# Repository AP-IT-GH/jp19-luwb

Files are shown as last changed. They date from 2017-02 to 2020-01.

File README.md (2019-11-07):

# Internet Of Things - *Location Ultra Wide Band*

## Angular
Build Status (https://dev.azure.com/LUWB/LUWB/_build/latest?definitionId=1&branchName=master)

## API
Build Status (https://dev.azure.com/LUWB/LUWB/_build/latest?definitionId=2&branchName=master)

**Teammembers**
* Hector Brasfalean
* Davy Cools
* Jens Peeters

## Summary
*Het lokaliseren van een robot/drone (indoor) door middel van Ultra Wide Band technologie. Dit gaan we visueel weergeven. We zullen de robot/drone ook op een autonome manier kunnen verplaatsen.*

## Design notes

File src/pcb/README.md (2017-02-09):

# PCB

In deze map verzamel je op een gestructueerde manier de bron bestanden voor het
PCB ontwerp.

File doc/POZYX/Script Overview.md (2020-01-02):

# Script Overview
## Dit is de documentatie van de POZYX Scripts
Onder src/Pozyx vind je 3 mappen met scripts het gebruik ervan wordt hieronder uitgelegd.

## 1 PozyxSoftware
Om deze scripts te gebruiken moet de Pozyx software aan het runnen zijn op een computer en moet er een Pozyx toestel met USB-kabel verbonden zijn.

### 1.1 connectLocal.py
Dit script verbind met de Pozyx software op een computer in het lokale netwerk.
Het print de coördinaten in de terminal en kan deze exporteren naar een txt-file.
Het IP-adres van de host waar de software op draait moet ingevuld worden onder host.

### 1.2 connectCloud.py
Dit script verbind met de software via de cloud gebruik makend van een topic, username en password.
Daarna worden de coördinaten geprint in de terminal.
Het topic, username en password moeten in het script ingevuld worden, en kan men vinden in de Pozyx software.

## 2 PozyxRPi
Dit zijn vooral test scripts en worden niet meer gebruikt.

### 2.1 pyTest.py
Dit script kijkt of er een Pozyx toestel is aangesloten.
Als er geen error wordt gegeven is alles in orde en is het toestel juist verbonden.

### 2.2 readingData.py
Kijkt na of het succesvol data uit het toestel kan halen.
Als "0x43" wordt geprint is alles in orde.

### 2.3 UWBsettings.py
Dit script haalt de UWB instellingen uit het toestel en print deze.

### 2.4 positioning.py
Dit script haalt de positie uit de direct verbonden tag en print dit af in de terminal.
De coördinaten kunnen ook geëxporteerd worden naar een txt-file

## 3 PozyxStandalone
Dit zijn de scripts waar we gebruik van maken en die niet afhankelijk zijn van de Pozyx software.
Bij de meeste scripts moeten er dingen worden ingesteld, hiervoor maken we gebruik van config-files.

### 3.1 Config-files
Omdat de meeste scripts dezelfde instellingen nodig hebben, zijn er config-files.

Er zijn 2 soorten files:

1. scripts die de vragen stellen over de instellingen
2. ini-files waarin de instellingen worden opgeslagen

We hebben 2 aparte config-files gemaakt:

1. Coördinaten en de ID's 
2. Exporteren

#### 3.1.1 createConfigFile.py
Dit script stelt de vragen voor de coördinaten en ID's:

1. Geconnecteerde toestel
2. Remote toestel(Meestal de tag)
3. ID's en coördinaten van de anchors

Deze slaagt deze waarden dan op in config.ini.

#### 3.1.2 config.ini
Hierin worden de ingestelde waarden van createConfigFile.py opgeslagen.
En deze file wordt gelezen door al de scripts die de coördinaten en ID's nodig hebben.

#### 3.1.3 createExportFile.py
Dit script stelt de vragen over het exporteren:

1. Exporteren naar een file?
2. Naam van de file
3. Exporteren via MQTT?
4. MQTT Host
5. MQTT Topic
6. MQTT ClientID
7. Exporteren via API?
8. API URL
9. API MAC Name

Deze slaagt al deze waarden dan op in export.ini

#### 3.1.4 export.ini
Hierin worden de ingesltelde waarden van createExportFile.py opgeslagen.
Deze file wordt dan ingelezen door de scripts die de export-settings nodig hebben.

### 3.2 Scripts
Hier staan de scripts die iets uitvoeren op het Pozyx toestel.

#### 3.2.1 discoverDevices.py
Het zoekt naar al de Pozyx toestellen binnen bereik met dezelfde UWB-instellingen vanuit het standpunt van het geconnecteerde toestel.
En print deze naar de terminal.

#### 3.2.2 setCoordinates.py
Dit script zet de ingestelde coördinaten in het geheugen van die toestellen.
Daarna worden al de coördinaten nog geprint ter controle.
Hierna kan getCoordinates.py uitgevoerd worden.
Dit is niet nodig voor positioning.

#### 3.2.3 getCoordinates.py
Deze haalt de coördinaten van de toestellen uit het geheugen van die toestellen en print deze naar de terminal.
Dit kan gebruikt worden na setCoordinates.py.

#### 3.2.4 setupAnchors.py
Dit wordt uitgevoerd op het remote device (tag).
Eerst wordt de device list leeg gemaakt. Daarna worden de ID's en coördinaten van de anchors opgeslagen in het geheugen van het device.
Optioneel kan dit worden opgeslagen in het flash-geheugen, maar dit staat in commentaar voor test doeleinden.
Hierna kan getDeviceCoordinates.py worden uitgevoerd.
Dit is nodig om positioning te kunnen uitvoeren.

#### 3.2.5 getDeviceCoordinates.py
Dit script wordt uitgevoerd op het remote device (tag).
Deze haalt de coördinaten van de anchors uit het geheugen van het device en print deze in de terminal.
Dit kan worden uitgevoerd na setupAnchors.py

#### 3.2.6 positioningTag.py
Dit is het belangrijkste script.
Dit wordt uitgevoerd op het remote device (tag).
Om dit script te kunnen uitvoeren moet setupAnchors.py eerst uitgevoerd zijn.
Eerst wordt de positie van de tag berekend en wordt die geprint naar de terminal.
Vervolgens wordt afhankelijk van de export-settings de positie geëxporteerd naar een file, via MQTT of naar de API.
Dit script zit in een loop en dient manueel gestopt te worden.

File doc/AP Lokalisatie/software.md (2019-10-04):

# 1. Software
## 1.1 Gebruikte software
-	Tag + anchors met Arduino (C/C++)
-	Data wordt doorgestuurd door de Raspberry Pi (python script)
-	Data wordt opgeslagen in een ASP.NET server
-	Data wordt visueel weergegeven in Angular
## 1.2 Software structuur
### 1.2.1 Tag en Anchor
Via de DWM1000 chips wordt de afstand tot de tag bepaald. De anchors die gebruik maken van een Arduino Pro Mini sturen hun data door over een Ethernet kabel naar het adres 192.168.3.3. De data wordt verstuurd in JSON formaat en ziet er als volgt uit:  
{"MAC_TAG":"TAGx","MAC_ANCHOR":"ANCHORy","DISTANCE":z}  
Met: x het tagnummer, y het anchornummer en z de afstand van de anchor tot aan de tag  
Voorbeeld: {"MAC_TAG":"TAG5","MAC_ANCHOR":"ANCHOR1", "DISTANCE":5}
### 1.2.2 Raspberry Pi
De Raspberry Pi doet 2 dingen. Langs de ene kant slaagt deze de data via een php apache server op en langs de andere kant stuurt deze de data door via MQTT.
#### Oude manier
- Het index.php bestand slaat bij een POST van data de data op als volgt:
1. Maakt de map data aan in /var/www/html indien deze nog niet bestaat.
2. Maakt in de map data een map TAGx aan met x = het tagnummer in de data van de POST indien deze nog niet bestaat.
3. Maakt in de map TAGx een bestand ANCHORy aan met y = het anchornummer in de data van de POST indien deze nog niet bestaat.
4. Schrijft in het bestand ANCHORy de afstand samen met datum op. Deze data wordt opgeslagen in het volgende formaat:   
distance,unixtimestamp  
Met: distance de afstand van anchor naar tag en unixtimestamp de datum  
Voorbeeld: 5,1557920157  
- Het postscriptMQTT.py stuurt de data door via MQTT om de 200 ms.
1. Leest de mappen uit die zich in de data map bevinden (/var/www/html/data).
2. Het script staat ingesteld om enkel de data uit de map TAG5 te lezen.
3. Alle bestanden in de TAG5 worden uitgelezen en de data wordt doorgestuurt via MQTT in het volgende formaat:   
TAGx;ANCHORy;distance;unixtimestamp
Met: x het tagnummer, y het anchornummer, distance de afstand van anchor naar tag en unixtimestamp de datum  
Voorbeeld: TAG5;ANCHOR1;25;1557475973
#### Nieuwe manier (voorkeur)
- Het listenAndPostScriptMQTT.py script luistert naar de socket. Stuurt bij het ontvangen van data de data door via MQTT.
1. Leest de config.ini file uit voor configuratie.
2. Luistert naar de socket op ingestelde ip + poort.
3. Stuurt de ontvangen data door via MQTT naar de ingestelde topic.
Het formaat van de doorgestuurde data is:
TAGx;ANCHORy;distance;unixtimestamp
Met: x het tagnummer, y het anchornummer, distance de afstand van anchor naar tag en unixtimestamp de datum  
Voorbeeld: TAG5;ANCHOR1;25;1557475973
### 1.2.3 ASP.NET server
De ASP.NET server haalt de data op van MQTT. Deze data wordt dan opgeslagen in de database.
### 1.2.4 Webapplicatie met Angular framework
Op de website wordt visueel weergegeven waar de tag zich bevindt t.o.v. de anchors.

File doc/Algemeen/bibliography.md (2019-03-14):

# 1	Sensor
## 1.1	Protocol
Pozyx creator tutorial gebruik makend van arduino: https://www.pozyx.io/documentation/creator/arduino/ready-to-range  
TWR vs TDOA:  
https://www.pozyx.io/pozyx-academy/positioning-protocols-explained  
https://www.infsoft.com/blog-en/articleid/305/uwb-two-localization-techniques-in-comparison  
TWR verklaring: https://www.sewio.net/uwb-technology/two-way-ranging/  
T(D)oa verklaring: https://sites.tufts.edu/eeseniordesignhandbook/files/2017/05/FireBrick_OKeefe_F1.pdf  
Arduino Motor uitleg: https://howtomechatronics.com/tutorials/arduino/arduino-dc-motor-control-tutorial-l298n-pwm-h-bridge/  
Arduino motor Tutorial: https://hackerstore.nl/PDFs/Tutorial298.pdf

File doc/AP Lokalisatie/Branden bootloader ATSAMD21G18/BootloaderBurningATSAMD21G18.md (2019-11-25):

# Stappenplan branden bootloader ATSAMD21G18

## 1. Installeren software
Voor het branden van de bootloader hebben we een bepaald programma nodig genaamd 'Atmel Studio'. 
De URL waar u dit programma kan downloaden is het volgende : [https://www.microchip.com/mplab/avr-support/atmel-studio-7](https://www.microchip.com/mplab/avr-support/atmel-studio-7)
## 2. Downloaden bootloader github
U zal de volgende repository moeten downloaden zodat u de bootloader voor de ATSAMD21G18 ter beschikking heeft.
[https://github.com/sparkfun/SAMD21_Dev_Breakout](https://github.com/sparkfun/SAMD21_Dev_Breakout)
## 3. Aansluitingen hardware
U sluit de J-link EDU aan via usb op uw computer. U sluit de 20 pin naar 10 pin adapter (J-TAG) aan op de J-link EDU. Vervolgens sluit je de ribbon cable aan op de adapter. De volgende signalen zijn de belangrijkste bij het aansluiten van de header:

 - SWDIO ( Grijze female jumper )
 - SWCLK ( Witte female jumper ) 
 - GND ( Paarse en groene female jumper ) 
 - VCC ( Gele female jumper ) 
 - RESET ( Blauwe female jumper ) 
 
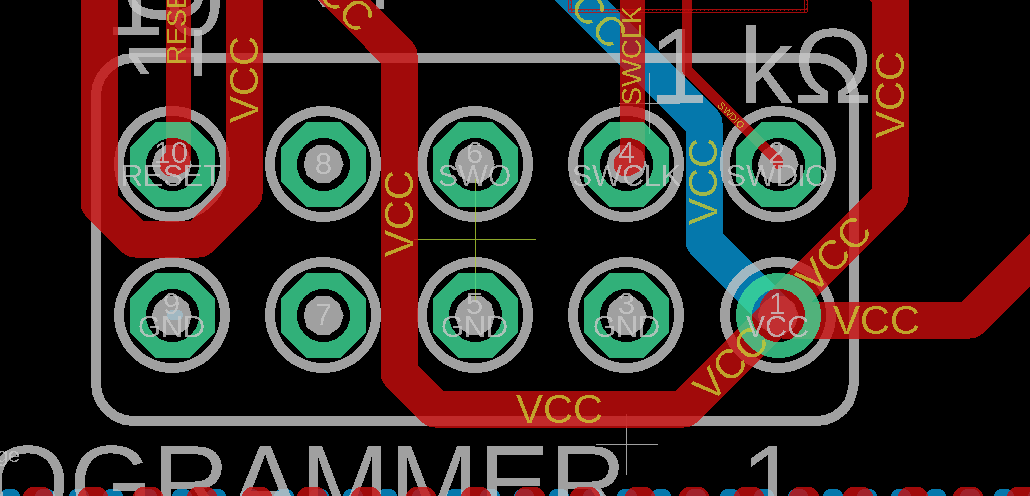
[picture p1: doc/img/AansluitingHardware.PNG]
Aansluitingen hardware

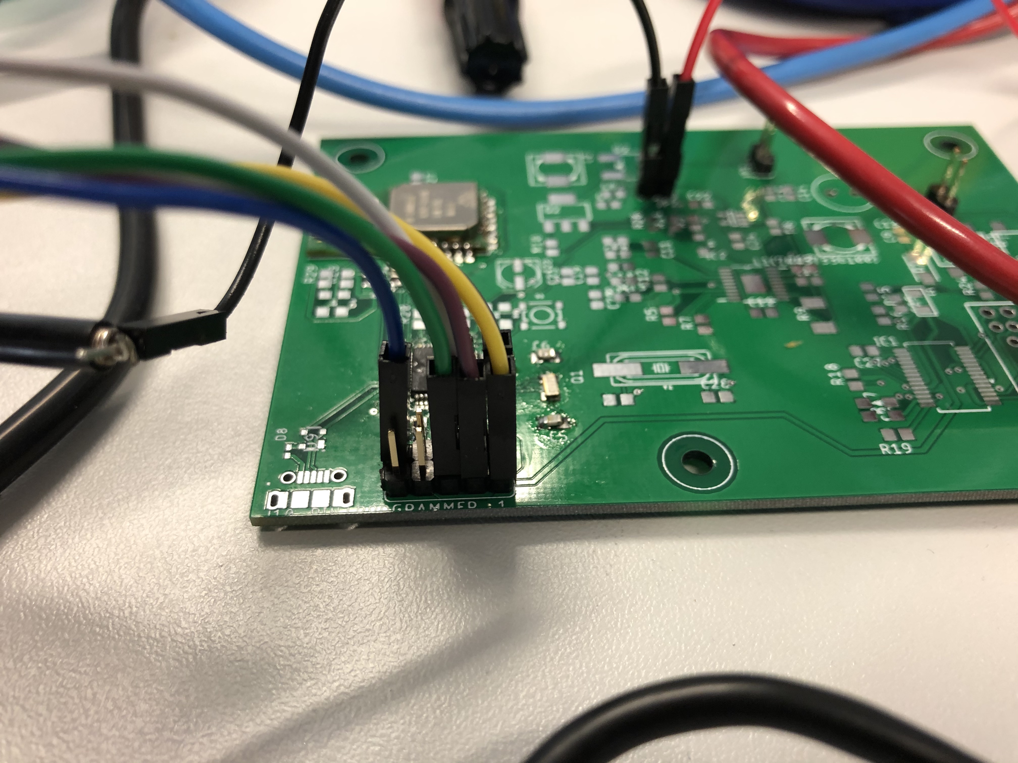
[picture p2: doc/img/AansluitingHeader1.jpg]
Aansluitingen hardware 1

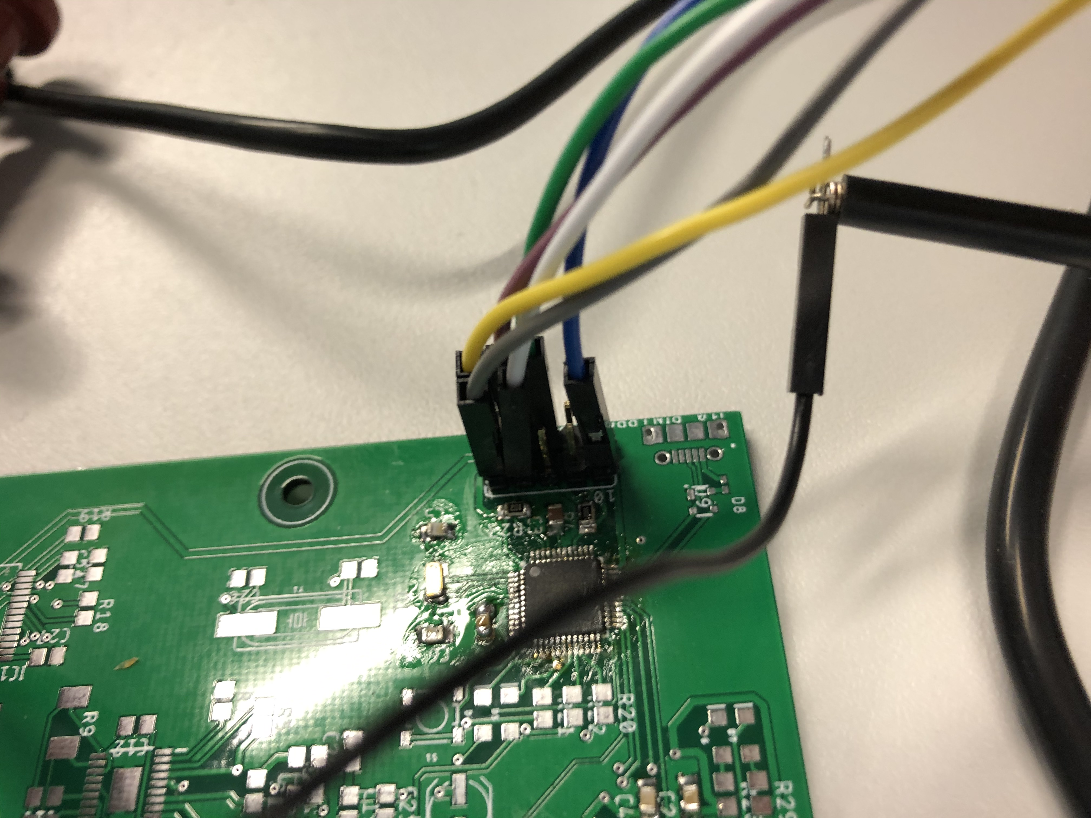
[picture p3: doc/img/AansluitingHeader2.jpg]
Aansluitingen hardware 2

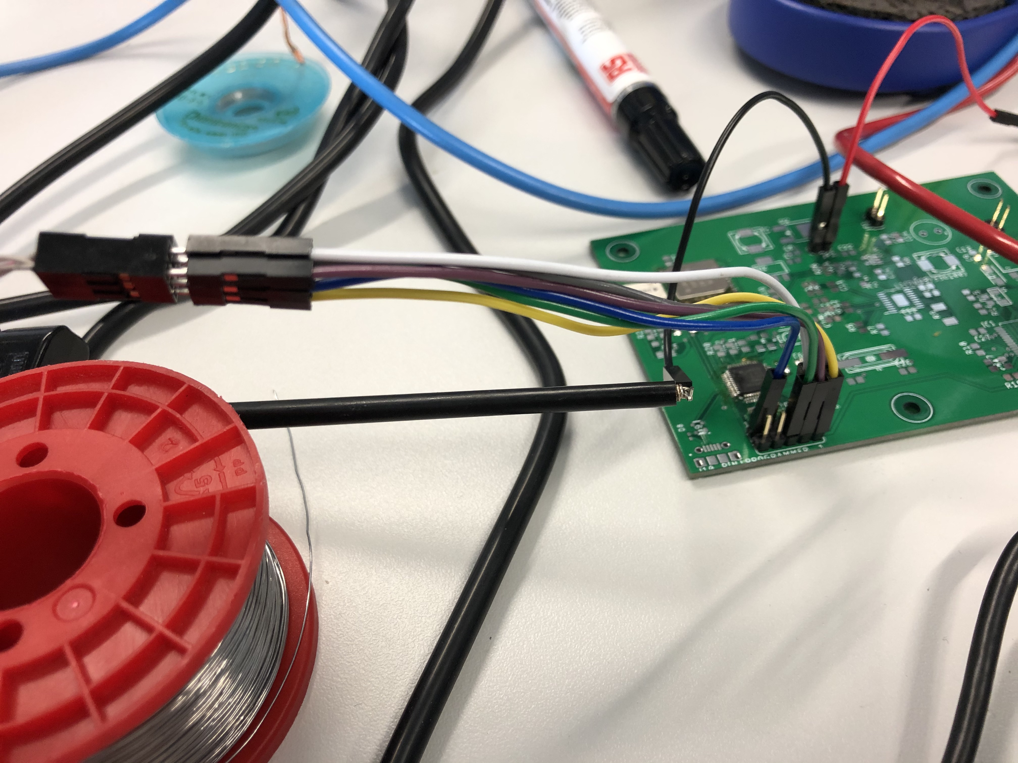
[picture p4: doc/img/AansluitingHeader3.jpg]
Aansluitingen hardware 3


## 4. Verwijderen ATSAMD21G18 chip
Zodra het programma geïnstalleerd is, zal u indien u het programma opstart het volgende scherm bekomen:
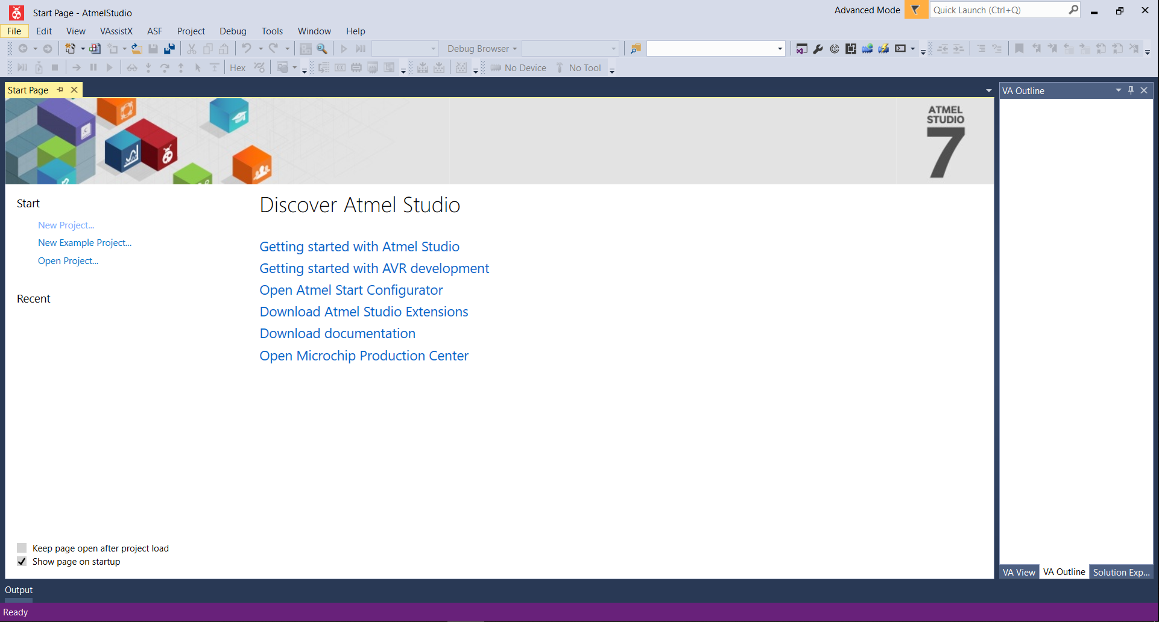
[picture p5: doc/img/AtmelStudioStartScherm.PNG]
Atmel Studio start scherm


Vanuit dit scherm gaat u naar **'Tools => Device programming'**. 
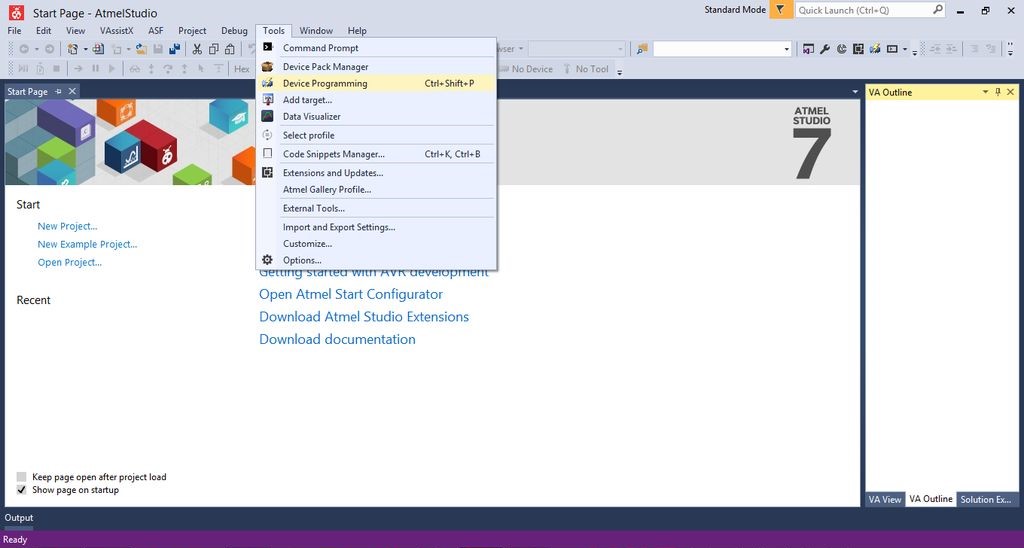
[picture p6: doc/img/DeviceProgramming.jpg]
Atmel Studio tools


Een nieuw venster zal verschijnen. Nu kan u uw J-LINK EDU connecteren met uw laptop via een USB-poort. Het resultaat zou moeten zijn dat u bij het nieuwe scherm onder **'Tool'** een drop-down heeft, in deze drop-down zou dan de J-LINK moeten staan. Deze kan u dan ook selecteren.
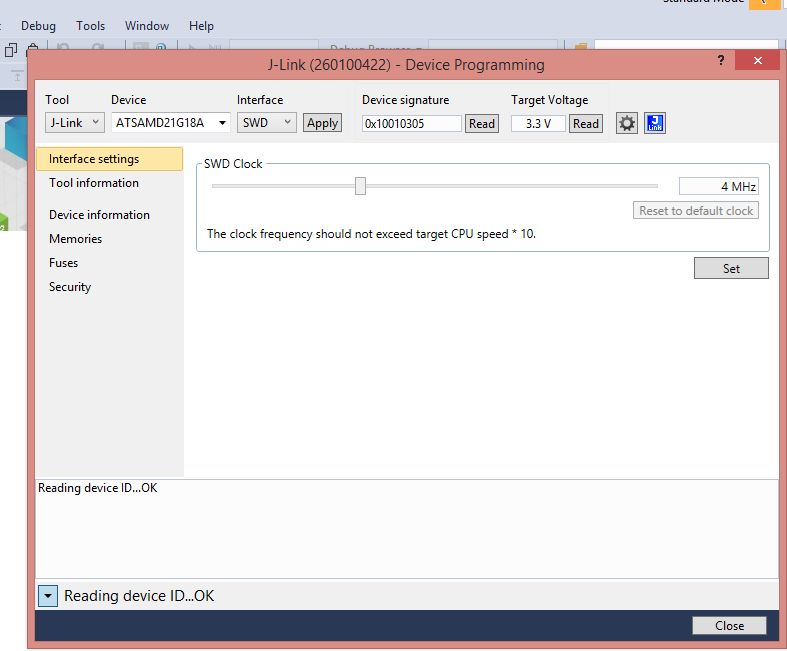
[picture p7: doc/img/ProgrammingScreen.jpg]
Atmel Studio programming


Bij de term **'Interface'** moeten we ook specificeren welke interface we zullen gebruiken. Deze moet ingesteld staan op **'SWD'**. Hierna kan u op **'Apply'** drukken.

Indien alles correct aangesloten zou zijn, moet u de ATSAMD21G18 zelf van spanning voorzien ( 3.3V ). Nadat u dit gedaan hebt, kan u onder de term **'Target Voltage'** de knop **'Read'** indrukken. Als alles correct aangesloten zou zijn moet u hier 3.3V uitlezen. Indien er wat onduidelijk is, verwijs ik naar de foto hierboven vermeld.

Vervolgens gaat u naar **'memories'** aan de linkerkant van uw scherm en zal u de chip verwijderen. U doet dit door **'erase chip'** te selecteren uit de drop-down en vervolgens op de knop **'erase'** te drukken. Op het output scherm zou u het volgende moeten bekomen : "Erase...Ok".
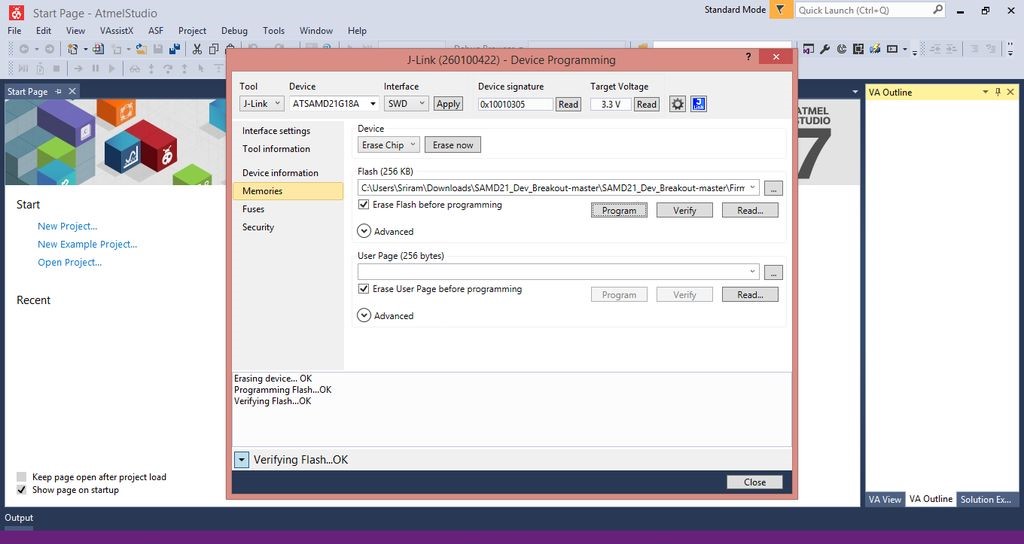
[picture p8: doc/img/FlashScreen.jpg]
Atmel Studio erase


## 5. Branden bootloader
Nu kan u de zekeringen of **'fuses'** programmeren bij de **'interface settings'** aan de linkerkant van het scherm. Dit doet u door naar het 'fuses' scherm te gaan en op de knop **'program'** te drukken. Dit verifieert de interne registers van de ATSAMD21-chip.
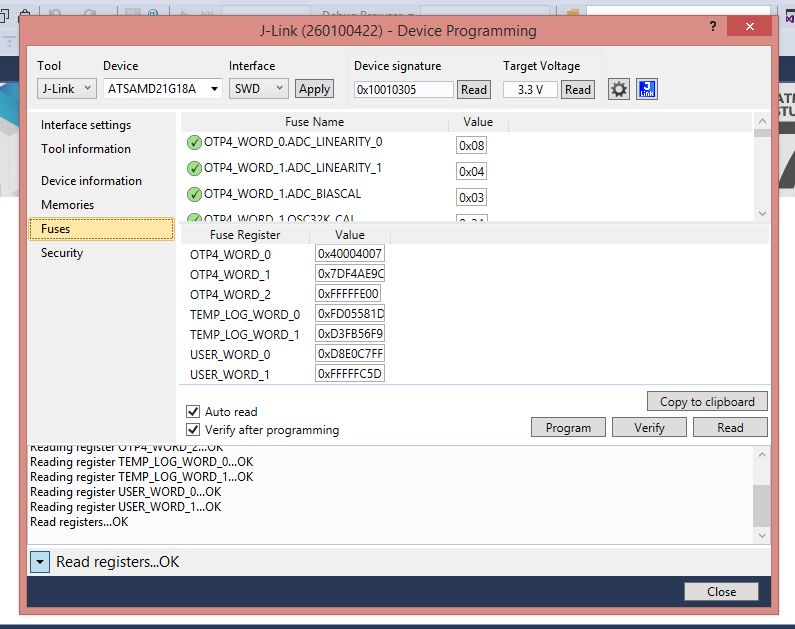
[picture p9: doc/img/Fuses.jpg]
Atmel Studio fuses


Uiteidenlijk gaan we terug naar het menu **'memories'**. Klik onder de balk met het label **'flash'** op het pictogram **'Bladeren naar bestand'** en zoek de map waarin u het zip bestand hebt opgehaald dat u van github hebt gekregen met het label "SAMD21_Dev_Breakout-master" onder Firmware, zorg ervoor dat u naar alle bestandstypes zoekt, want we zullen het samd21_sam_ba_sparkfun.bin bestand gebruiken. Klik op het bestand en selecteer openen. Klik ten slotte op de knop **'Program'** en u krijgt een antwoord in het output scherm met de melding: "Verifying Flash...OK". Gefeliciteerd, je hebt de SAMD21-chip succesvol opgestart!

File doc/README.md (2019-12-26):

# Documentatie
# Algemeen
Alle algemene informatie vindt u in de folder Algemeen. Dit gaat over de gebruikte techniek, wat LUWB is, de bibliografie, ...

# Project AP Lokalisatie
Alle info in verband met het zelf gemaakt project zit in de map AP Lokalisatie

# Project POZYX
Alle info in verband met het POZYX zit in de map POZYX

# De website en de server
Alle info in verband met de website en de server zit in de map Website en server

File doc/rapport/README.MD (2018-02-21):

Plaats in deze map alle documenten die deel uitmaken van je eindrapport

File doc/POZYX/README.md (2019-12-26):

# Documentatie

In deze map vindt u alle documentatie van het POZYX project.

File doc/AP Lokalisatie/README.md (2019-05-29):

# Documentatie

In deze map vindt u alle documentatie van het AP lokalisatie project.

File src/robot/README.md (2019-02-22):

# Robot

In deze map verzamel je op een gestructueerde manier de bron bestanden voor de
Robot applicatie.

SMART SYSTEMS KIT #19

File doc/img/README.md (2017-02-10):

# Images

Gebruik deze folder voor het verzamelen van afbeeldingen en maak een link naar het gewenste document.

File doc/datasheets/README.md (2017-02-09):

# Datasheets
In deze map verzamel je de gebruikte datasheets. Upload ze als pdf.

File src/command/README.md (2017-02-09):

# Command Center

In deze map verzamel je op een gestructueerde manier de bron bestanden voor de
Command Center applicatie.

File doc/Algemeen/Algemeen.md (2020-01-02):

# Location Ultra Wide Band
## 1 Wat is UWB?
UWB (Ultra Wide Band) is een draadloze technologie die gebruikt wordt om met hoge snelheid grote hoeveelheid data door te sturen. Het UWB signaal is zeer robust en kan door dunne muren. Wij gebruiken deze techniek voor het localiseren van een beweegbaar object (drone/robot). 

## 2 Algemene begrippen/technologiën
### 2.1 MQTT
MQTT staat voor Message Queueing Telemetry Transport. Dit is een machine-tot-machine data transfer protocol. MQTT is gebasseerd op TCP/IP en heeft een kleine overhead (2-byte header). MQTT heeft een centrale bemiddelaar, de MQTT-broker. Deze interface is voor alle verzonden berichten. De betrokken apparaten communiceren dus niet met elkaar en kennen elkaar dus onderling niet. Het is de taak van de broker om berichten te accepteren en door te geven aan de juiste ontvanger(s).

### 2.2 DWM module
De DWM module, of specifieker de DWM1000 module is gebasseerd op Decawave's DW1000 IC. Deze module maakt het mogelijk om objecten real-time te lokaliseren (RTLS: real time location systems) tot op een nauwkeurigheid van 10cm binnen. De datacommunicatie kan gaan tot een snelheid van 6,8 Mbps met een bereik tot 300 meter. 

### 2.3 SQL
SQL staat voor Structured Query Language. Dit is een ANSI/ISO-standaardtaal voor databasemanagement systemen (DBMS). Dit is dus een gestandaliseerde taal die gebruikt wordt voor het opslagen, opvragen, aanpassen en verwijderen van gegevens in een relationele database.

### 2.4 Relationele Database
Een relationele database is een database die is opgebouwd volgens het relationeel model. Alle gegevens worden opgeslagen in tabellen waarbij rijen de soortgelijke informatie (records) vormen en de kolommen zijn de informatie die voor elk record moet worden opgeslagen. Verschillende tabbellen kunnen met elkaar verbonden worden door een extra kolom waarin een verwijzing staat naar een record van een andere tabel.

## 3 De 2 projecten
### 3.1 Project 1: LUWB self-made
Dit project is een eigen ontworpen systeem dat gebruik maakt van de UWB technologie. De bedoeling is dat we met zelfgemaakte anchors een robot kunnen localiseren met een tag aan boord. De tag communiceerd dan met de anchors en er wordt berekend hoe ver deze zich van elkaar bevinden. Op basis hiervan wordt dan berekend waar de robot zich op dat moment bevindt. Dit wordt dan visueel weergegeven.

#### 3.1.1 Hoe werkt het?
##### 1. Huidig concept:
De tag (robot) die werkt op een Arduino met een DWM module communiceerd met de anchors die werken op 2 Arduino's met een DWM module. Deze 2 delen dan informatie met elkaar uit via UWB en zo wordt er bepaald wat de afstand is tussen de tag en de anchors. Deze data wordt doorgestuurd over een ethernetkabel naar een switch en komt terecht bij een Raspberry Pi. Op deze Raspberry draait dan een script die deze data op zijn beurt doorstuurt via MQTT. Een server die lokaal of op een cloud draait lijst dan deze data uit en slaagt deze op in een SQL database. Met deze data wordt er berekend waar de tag (robot) zich exact bevindt.  Dan wordt vanuit een webapplicatie die gemaakt is met Angular de data opgevraagd. Dit wordt dan visueel weergegeven op de website.

#### 2. Veranderingen die zijn gebeurd:
De data werd eerst rechtstreeks doorgestuurd naar de server die in de cloud stond via threading in het python script. Dit zorgde voor verschillende problemen en werkte vrij traag. Ook was het luisteren naar de socket via een apache server niet de beste manier.
Dit is vervangen door 1 enkel pythonscript die luistert naar de socket en de data doorstuurd via MQTT. De server die op het moment lokaal draait op een laptop wacht op zijn beurt af tot er nieuwe MQTT data beschikbaar is.

#### 3. Veranderingen die nog moeten gebeuren:
1. Op het moment werken de anchors op 2 arduino's. Deze worden vervangen door 1 enkele chip genaamd atsamd21g18.
2. Het voorzien van spanning via een adapter wordt vervangen door PoE (Power over Ethernet).
3. Het visueel weergeven moet zowel op een website als op een app kunnen weergegeven worden.
4. De drone of robot moet kunnen worden bestuurd via de app/website door een lijn te tekenen en deze dan te laten volgen. Voorlopig kan de robot via een aparte app wel verplaatst worden door middel van 4 knoppen (voorruit/achterruit/links/rechts).

### 3.2 Project 2: Pozyx
Dit is een systeem van Belgische makelij dat we hebben aangekocht. Dit systeem maakt ook gebruik van UWB. De bedoeling was dat we de tag op een robot konden plaatsen en deze dan zo kunnen traceren. We hebben het systeem op 2 wijze gebruikt nl. Out-Of-The-Box: waarvoor het gemaakt is. En met onze zelfgemaakte software.

#### 3.2.1 Out-Of-The-Box
Het systeem is gemaakt om snel bruikbaar te zijn door middel van de bijhorende Pozyx software. De software moet geïnstalleerd worden op een computer en deze moet verbonden worden met 1 van de Pozyx toestellen. De andere toestellen moeten gewoon van stroom voorzien worden en zullen allemaal met elkaar communiceren. In de software worden dan alle toestellen weergegeven. En kan je autocalibratie laten uitvoeren, maar dit is niet accuraat dus is manuele calibratie aanbevolen. Vervolgens kan de tag gelocaliseerd worden en wordt dit getoont op de kaart. Ook kan de positie geëxporteerd worden via MQTT over het lokale netwerk of via de cloud.

#### 3.2.2 Zelfgemaakte software
Omdat we niet afhankelijk wouden zijn van de Pozyx software, hebben we zelf software geschreven in de vorm van Python scripts die dan wel de Pozyx hardware gebruikt. Er zijn scripts geschreven die nog afhakelijk waren van de Pozyx software voor testen, maar nu zijn er script die volledig onafhankelijk zijn van de software. Om het systeem te gebruiken moeten al de anchors worden geïnstaleerd. 1 anchor moet met een USB-kabel worden aangesloten aan een Raspberry Pi. Al de andere anchors moeten van stroom worden voorzien. Vervolgens moet je met ons config script alle coördinaten en ID's van de anchors instellen. Daarna voer je de setup uit op de tag als deze van stroom is voorzien. En dan is het mogelijk om de positie van de tag te bepalen. Die positie wordt in de terminal geprint en kan ook afhankelijk van de export-instellingen, worden geëxporteerd naar een file, via MQTT of naar de API welke dan zichtbaar is op de website.

# Bronnen:
- POZYX: [pozyx](https://www.pozyx.io/)
- MQTT: [at-automation](https://www.at-automation.nl/knowledge-base/mqtt-message-queueing-telemetry-transport-wat-is-het/) [ct](https://www.ct.nl/achtergrond/iot-protocol-mqtt-betrouwbaar-data/)
- DWM: [decawave](https://www.decawave.com/product/dwm1000-module/) 
- SQL: [wikipedia](https://nl.wikipedia.org/wiki/SQL) 
- Relationele Database: [wikipedia](https://nl.wikipedia.org/wiki/Relationele_database)

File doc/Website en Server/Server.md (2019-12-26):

# Documentatie van de server

**Topics die aan bod zullen komen**
- Algemene informatie
- Opstarten van de server
	- default connection string
	- SQL Server Object
- Doel van de controllers
- Belangrijke methode's

## Algemene informatie

Er is gebruik gemaakt van een ASP.NET Core REST API met versienummer 3.0. De server is helemaal klaar om online gehost te worden via Azure. De database kan zowel lokaal als online op Azure gehost worden. 

## Opstarten van de server

**Lokaal**
Bij het openen van de server is het aangeraden om gebruik te maken van Visual Studio 2019 of nieuwer. Het openen kan gemakkelijk door de solution Server.sln te openen, deze is te vinden in de map Server. Hierna moet je enkel nog op IIS Express klikken en de server zal opstarten, hierdoor zal database automatisch gegenereerd worden.

> **Note:** Zorg er voor dat de default connection string op de lokale database staat ingesteld. Meer informatie vindt je hieronder.

### Instellen van de default connection string

De default connection string beschrijft de locatie van de gebruikte database. Deze string vind je in de file 'appsettings.json'. Voor het gebruiken van een lokale database gebruik je volgende string:

**Server=(localdb)\\mssqllocaldb;Database=NaamDB**
NaamDB mag eender welke gekozen naam zijn voor de lokale database.

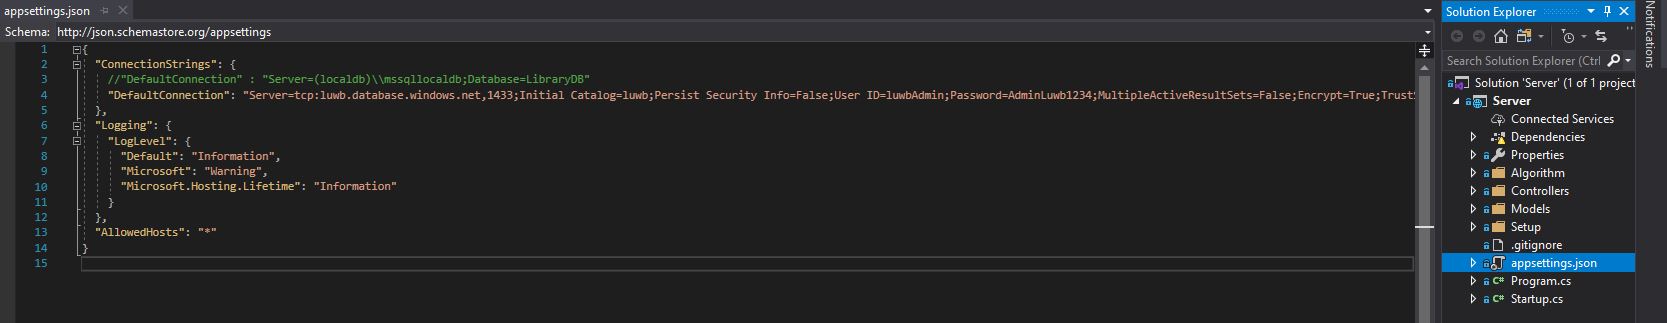
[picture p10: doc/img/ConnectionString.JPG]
ConnectionString


Voor het gebruiken van een online database moeten er verschillende variabele meegeven worden. Om te weten welke variabele je moet meegeven, moet je kijken in de documentatie van het gebruikte hostplatform. 

> **Note:** De 2de connection string in de server is voor een database gehost op Azure. Bij het gebruiken van deze string moet je enkel het id, passwoord en de locatie van de server aanpassen.

### Locatie van de lokale database
Als je gekozen hebt om de database lokaal op te slagen, kan je deze als volgt terugvinden:
- Open de server
- Ga naar **View** => **SQL Server Object Explorer**

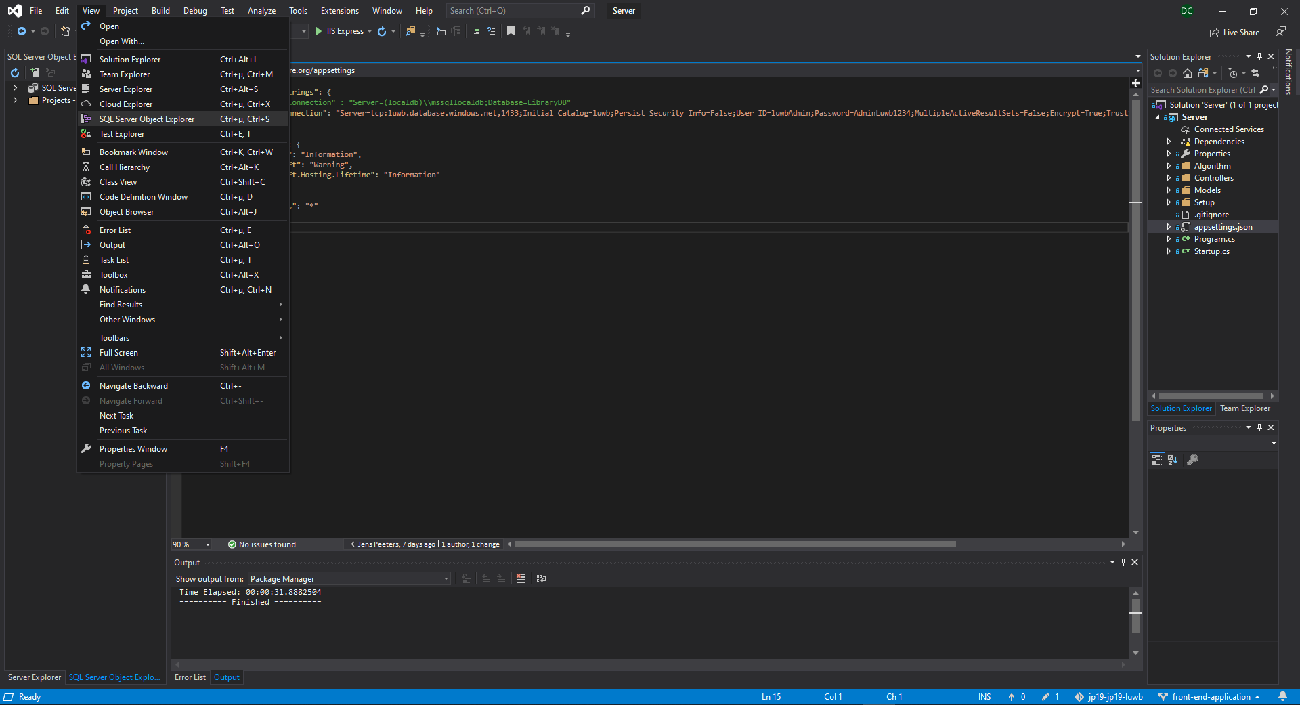
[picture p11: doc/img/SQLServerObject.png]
SQL Server Object


- Hierna open je de **SQL Server** => **Databases** => **{Gekozen DB naam}**

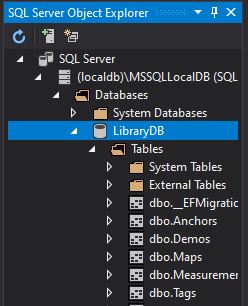
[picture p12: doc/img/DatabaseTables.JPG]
DatabaseTablest DatabaseTables


Alle data die in de database zit zal je ook hier kunnen terugvinden bij het debuggen.

## Doel van de controllers

### TagController
Via deze controller kan je alle tags aanspreken die opgeslagen zijn in de database alsook nieuwe tags toevoegen en bestaande tags verwijderen. Doel van de methodes:
- **GetTagsParam({parameters}):** Elke tag die voldoet aan de meegeven parameters zal worden teruggestuurd. Dit zal een lijst zijn van geen of meerdere tags.
- **GetTag(id:long):** Opvragen van 1 tag die de meegeven id bevat. De methode zal antwoorden met een NotFound als de tag niet gevonden is.
- **Addtag(tag: Tag):** Toevoegen van 1 tag die meegeven wordt in de body van de Post. De tag zal hier opgeslagen worden in de database.
- **UpdateTag(tag: Tag):** Updaten van de meegegeven tag. Als de meegeven tag niet bestaat in de database zal een NotFound worden teruggestuurd.
-  **UpdatePozyxTag(mac, xpos, ypos, zpos):** Updaten van de tag met meegegeven mac. Hierbij zal enkel de positie van de tag aangepast worden. Deze methode zal alleen worden opgeroepen door het Pozyx systeem.
- **DeleteTag(id: long):** Verwijderen van de meegeven tag. Wanner de tag succesvol is verwijderd zal een status 200 Ok worden teruggestuurd. Ook hier wordt een NotFound teruggestuurd bij een foute id.

### AnchorController
Via deze controller kan je alle anchors aanspreken die opgeslagen zijn in de database alsook nieuwe anchors toevoegen en bestaande anchors verwijderen. Doel van de methodes:
- **GetAnchorsParam({parameters}):** Elke anchor die voldoet aan de meegeven parameters zal worden teruggestuurd. Dit zal een lijst zijn van geen of meerdere anchors.
- **GetAnchor(id:long):** Opvragen van 1 anchor die de meegeven id bevat. De methode zal antwoorden met een NotFound als de anchor niet gevonden is.
- **AddAnchor(anchor: Anchor):** Toevoegen van 1 anchor die meegeven wordt in de body van de Post. De anchor zal hier opgeslagen worden in de database.
- **UpdateAnchor(anchor: Anchor):** Updaten van de meegegeven anchor. Als de meegeven anchor niet bestaat in de database zal een NotFound worden teruggestuurd.
- **DeleteAnchor(id: long):** Verwijderen van de meegeven anchor. Wanner de anchor succesvol is verwijderd zal een status 200 Ok worden teruggestuurd. Ook hier wordt een NotFound teruggestuurd bij een foute id.

### MeasurementController

- **CreateMeasurement(item: Measurement):** Toevoegen van 1 measurement die meegeven wordt in de body. Wanner zowel de tag als de anchor gevonden worden zal de measurement of worden geüpdate als deze al bestaat of worden toegevoegd. Als de tag of anchor ontbreekt zal er een NotFound worden teruggestuurd.
- **GetAllMeasurements():** Alle measurements zullen worden teruggestuurd in een lijst.
- **GetMeasurement(mac: string):** Opvragen van 1 specifieke measurement van een tag met als mac gelijk aan de meegegeven mac. De gevonden measurement zal dan worden teruggestuurd. Als er geen measurement gevonden is wordt er een NotFound teruggestuurd.

## Belangrijke methode's
**! Opgelet: Alles van MQTT wordt niet meer gebruikt, voor dit terug te kunnen gebruiken moet alles in de startup.cs uit commentaar gehaald worden waarbij het volgende staat geschreven: 'Disabled MQTT'.  Dit wordt niet meer gebruikt omdat bij het hosten bij Azure het gratis abonnement slechts 1 uur uptime geeft per dag en MQTT blijft 24/7 draaien, het nieuwe gebruikte systeem met post niet. !**

In de startup.cs: 

- **SetupMQTT():** Hier worden alle gegevens die nodig zijn voor MQTT opgehaald uit een bestand. Dit wordt niet meer gebruikt omdat we dit bestand niet mee uploaden naar Azure. De gegevens worden dus gewoon in de startup.cs klasse ingevuld.
- **client_MqttMsgPublishReceived(sender: object, e:MqttMsgPublishEventArgs):** Wordt getriggerd wanneer er een bericht gepubliceerd wordt op de MQTT topic
- **ConnectToBroker():** Connectie maken met de MQTT broker en subscriben op de ingestelde topic
- **SaveMeasurementInDB(payload: string):** Wanneer er een bericht op de MQTT wordt gepost, wordt er gecontroleerd of dit in het juiste formaat is. Wanneer het formaat overeenkomt zal de measurement worden geüpdate of aangepast wanneer deze nog niet bestond. Hierna wordt er gekeken of alle measurements van de tag in de meegestuurde measurement van hetzelfde tijdstip zijn. Als dit zo is zal de locatie van de tag opnieuw berekend worden.

In de Algorithm.cs:
- **Calculate(dataList: List<Data>):** Een data object bevat de afstand van een anchor tot een tag samen met zijn huidige locatie. Deze worden dan meegegeven naar de juiste methode. Voorlopig is dit slechts 1 methode.
- **calculateThreeCircleIntersection(x,y,r (3 keer)):** Deze methode berekend de locatie van de tag. Deze methode zal alleen maar weken bij 2 of 3 anchors. Bij het gebruik van meer anchors moet er een nieuwe methode worden aangemaakt.

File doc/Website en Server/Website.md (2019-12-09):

# Documentatie van de website

**Topics die aan bod zullen komen**
- Algemene informatie
- Opstarten van de website
- De verschillende componenten
- De verschillende services

## Algemene informatie

Deze server is gemaakt in Angular. Je kan deze files aanpassen en bekijken met verschillende programma's. Wij raden aan om het te openen met Visual Studio Code. De naam van de folder waar alle files zich bevinden is WebAppLUWB me als path \src\visualisatie\WebAppLUWB.

## Opstarten van de website
**Lokaal**
- Installeren van de dependencies: Voor het lokaal runnen van de website moet je de nodige dependencies en modules installeren. Hiervoor typ je 'npm install' in een terminal of Windows Powershell. 

> **Note:** Zorg er voor dat je bij dit en volgende commando's in de folder zelf zit of je in de terminal typt die je onderaan vindt bij Visual Studio Code.

- Het starten van de server kan zeer gemakkelijk door het commando 'npm start' in de terminal te typen. De webserver zal nu opstarten en je kan je website terugvinden onder het domein 'http://localhost:4200'. Je zal automatisch geredirected worden naar de homepage van de webserver (http://localhost:4200/home).

## De verschillende componenten

- **Home component:** Deze component bevat alle code voor het tonen van de home page. Op deze pagina vindt u een kleine samenvatting van de 2 projecten alsook een foto.
- **Map component:** Deze component bevat alle code voor het tonen van de map page. Hier worden alle anchors en tags getoond op een kaart.
- **PageNotFound component:** Deze component wordt weergegeven wanneer de gebruik een route ingeeft die niet bestaat.
- **TagsAndAnchors component:** Deze component bevat alle code voor het tonen van de anchors en tags in een lijst. Hier is het mogelijk anchors/tags te verwijderen/toevoegen/updaten.
- **Toolbar component:** Deze component bevat alle code voor het tonen van de toolbar. Dus wanneer er een nieuwe route nodig is of een bestaande wordt aangepast moet je de logica en de layout aanpassen in deze component. Via het [routerlink] attribuut kan je ingeven naar welke route er moet genavigeerd worden.

## De verschillende services

- **Callapi Service** Deze service wordt gebruikt voor alle gets/posts en puts naar de API. Hier is het dus belangrijk dat de variabele genaamd domain juist is ingesteld. Deze moet ingesteld zijn op de link waar de api zich bevindt.
> **Tip:** Als je de api lokaal runt zal dit de standaard link zijn en die is als volgt: https://localhost:44321/api/
> Na de laatste / komt de naam van de controller (bv.  https://localhost:44321/api/tags)

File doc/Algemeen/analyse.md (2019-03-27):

# Analyse

## Probleemstelling

Het indoor tracken van assets (drones/robots) door middel van een Ultra Wide Band (UWB) systeem dat we van scratch gaan maken.

## Deelproblemen

1.	Localisatie
-	Connecteren met de tag.
-	Bepalen van de x,y en z coördinaten van de tag.
2.	Visualisatie van anker en tag
-	Het visualiseren van de locatie van de tag ten opzichte van de anchors op een website.
-	De map moet juist gevisualiseerd moeten.
3.	Energieverbuik
-	Leveren van genoeg vermogen en proberen het vermogen van de anchors en tags zo klein mogelijk te houden.
4.	Nauwkeurigheid
-	Bij een te kleine omgeving is er slechte nauwkeurigheid.
-	Bepalen van de locatie zo nauwkeurig mogelijk.
5.	Verzenden van data
-	Zorgen dat de data aankomt naar de server.
6.	Beweging
-	De beweging van de tag d.m.v. robot/drone.
-	Bestuur afstand voor manuele beweging
7.	App
-	Het besturen van onze robot/drone.
-	De lokalisatie van de robot/drone zien.
8.	Database
-	Er moet een historiek van de data worden weergegeven.
9.	Omgeving
-	De omgeving mag niet te klein om onze functie te laten werken.
-	De omgeving is binnen.
10.	Snelheid
-	Snelheid van data
-	De robot/drone mag niet botsen tegen de muur of obstakel

## Mindmap
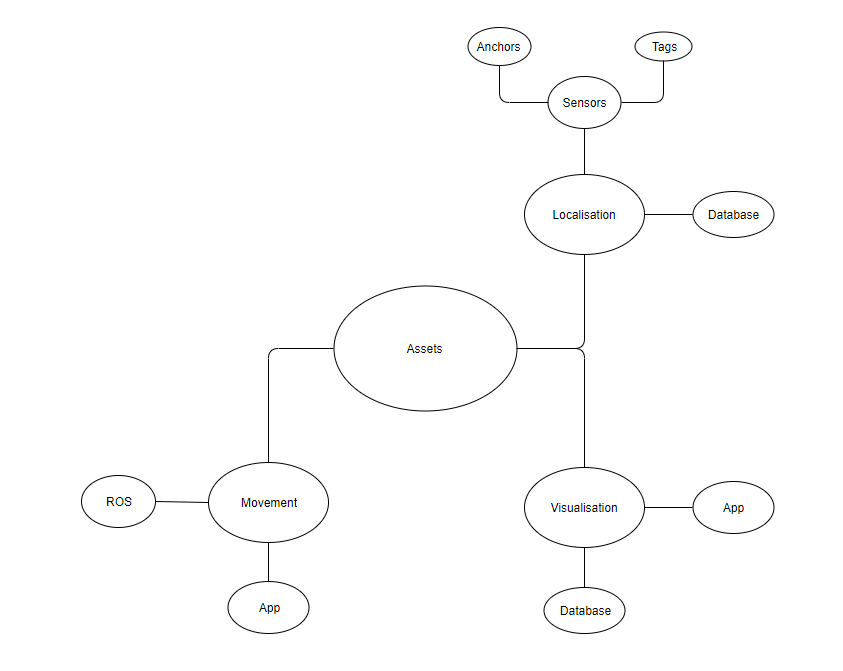
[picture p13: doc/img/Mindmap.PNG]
Github Logo Mindmap


## Beschrijving

Een transportbedrijf, dat ook goederen stockeert, wil analyseren of de workflow efficiënter kan. Dit zou kunnen door manueel te kijken of alle goederen efficiënt doorheen het bedrijf bewegen door bij elke verandering van plaats, dit op te schrijven en nadien dit te bekijken. Dit vergt natuurlijk een hele hoop administratie en manueel werk. We zouden een systeem kunnen opstellen dat alle goederen traceert binnen het bedrijf en dit logt naar een centrale database. We zouden in dit systeem gebruik kunnen maken van een drone, die vanuit een database alle locaties en dus ook routes kan ophalen en worden weergegeven op een plattegrond van het bedrijf via een mobiele app of website. De plaatsbepaling kan op enkele manieren gebeuren, maar omdat dit indoor is en toch wel een goede nauwkeurigheid vereist, is GPS geen optie. In dit geval zouden we gebruik kunnnen maken van UWB technologie. Ultra-wideband is een draadloze technologie waarmee een grote hoeveelheid gegevens bij een hoge snelheid kan worden verzonden. Dit is mogelijk door de gegevenspakketjes over een brede frequentieband te spreiden, waardoor ze parallel kunnen worden verzonden. Daardoor zijn gegevenssnelheden tot 1GB per seconde over een afstand van 10 meter mogelijk. De drone zal dan door het magazijn kunnen vliegen en gevisualiseerd worden via een website of een mobiele app en indien nodig, kunnen er bewegingen uitgevoerd worden door een beweging op het scherm van een smartphone. Om te beginnen gaan we testen met een kleine robot. Deze robot zal werken van op de grond.

## Hardware analyse

### Hardware blokdiagram

#### Tag

Github Logo Tag Blokschema

- ATmega328P
Een microcontroller wordt veel gebruikt in veel projecten en autonome systemen waarbij een eenvoudige, low-powered, low-cost microcontroller nodig is.

- DWM1000 (UWB modules)
De DWM1000 is een UWB module. Deze module maakt de locatie van objecten in realtime locatiesystemen (RTLS) tot een nauwkeurigheid van 10 cm binnenshuis mogelijk.

- Stepdown
De DC-DC-stepdown-module wordt gebruikt om de ingangsspanning en de uitgangsstabiele 5 volt spanning te verlagen.

- UART module
Deze module is om via Micro USB naar UART te gaan. 

#### Anchor

Github Logo Anchor Blokschema

- ETHERNET IC (ENC28J60)

- Crystal ENCJ2860 (25MHz)

- Crystal ATMEGA1 (8MHz)

- Stepdown
Zie Tag

- ATmega328P
Zie Tag

- DWM1000
Zie Tag

### Specificatie tabel

### Argumentatie en alternatieven tabel

## Software analyse

Plaats hier een flow-chart van de software. Hierin moet de werking van de software duidelijk worden weergegeven. Voorzie ook de nodige uitleg.

### Data In -en Outputs

### State diagram

#### State diagram mobiele app

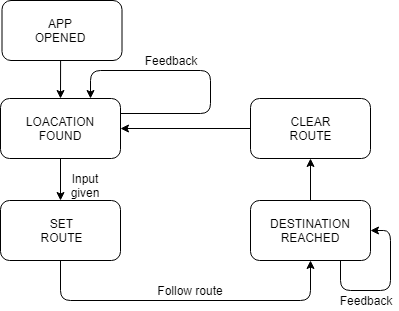
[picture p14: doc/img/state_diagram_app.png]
Github Logo State Diagram App

#### State diagram drone

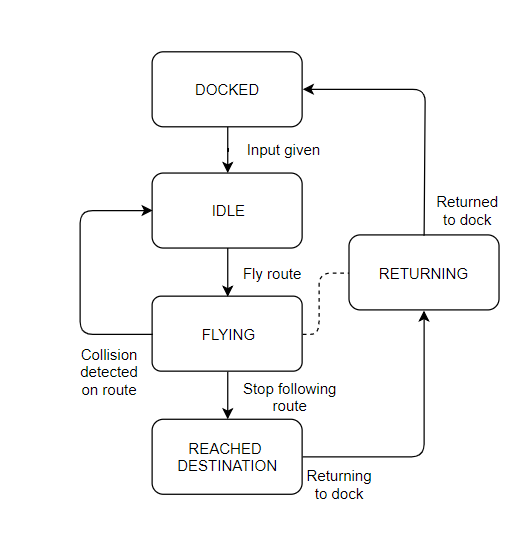
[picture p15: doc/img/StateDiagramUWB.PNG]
Github Logo State Diagram Drone

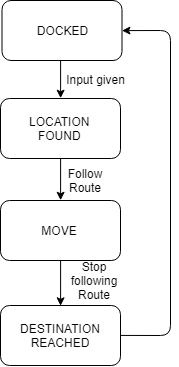
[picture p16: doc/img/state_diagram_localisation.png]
Github Logo State Diagram Localisation

### Flowchart
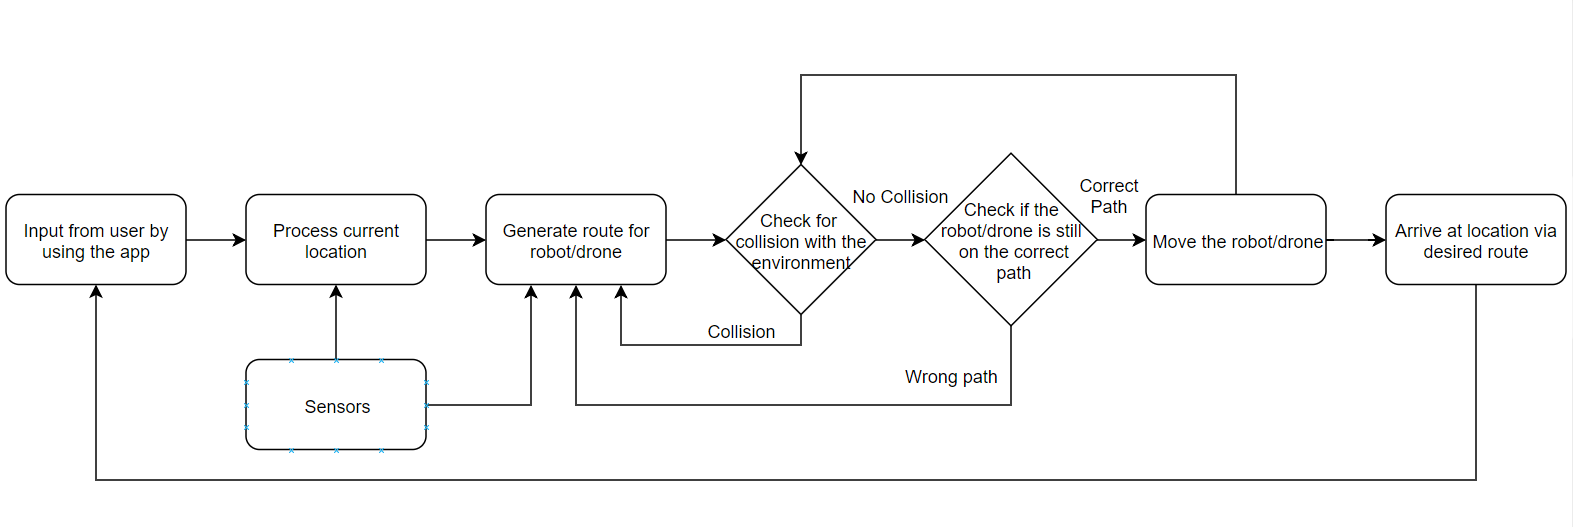
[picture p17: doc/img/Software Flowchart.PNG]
Github Logo Software Flowchart


### Mockup
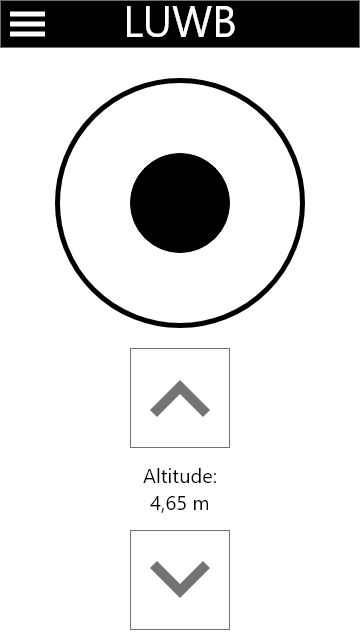
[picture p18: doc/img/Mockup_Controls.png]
Github Logo Mockup Controls

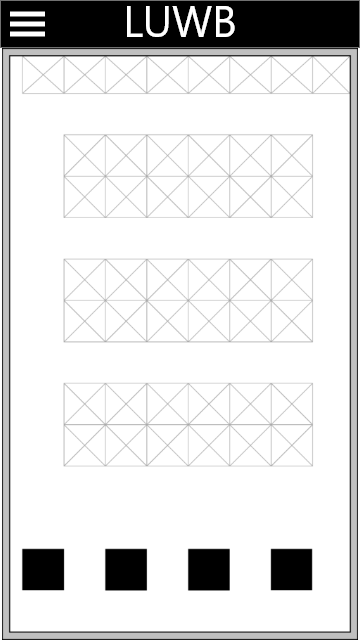
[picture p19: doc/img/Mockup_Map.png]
Github Logo Mockup Map


## User stories en Engineering Tasks

Geef hier de userstories en engineering tasks. De beschrijving moet conform zijn met de methode zoals gezien in de lessen  van projectmanagement vn dhr Peeters.

## systeemspecificaties

Geef hier de systeemspecificaties waaruit je de hardware en software kan ontwerpen

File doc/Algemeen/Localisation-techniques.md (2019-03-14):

# Lokalisatie technieken

## Two-way ranging

Deze techniek zendt pakketjes heen-en-weer tussen anchor en tag. Door de tijd tussen de signalen te bepalen kunnen we de afstand bepalen tussen anchor en tag. Deze tijd wordt de Time of Flight (ToF) genoemd. De afstand wordt bepaalt tussen de anchor en de tag, dus niet meteen het hele systeem maar de afstand tussen 1 van de anchors in het systeem. Zo kunnen we de afstand in een radius rond elke tag bepalen en zo de cirkels laten snijden om zo de locatie van de tag bepalen.

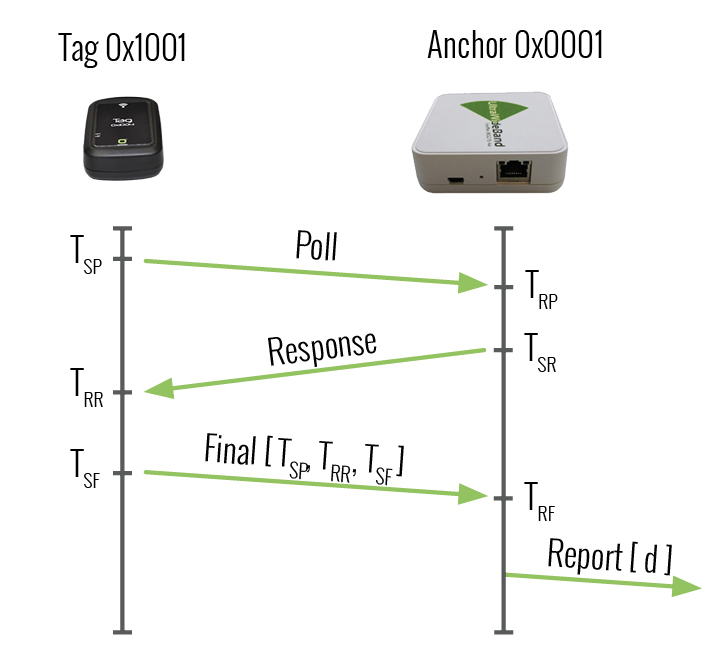
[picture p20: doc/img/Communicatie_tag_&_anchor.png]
Visuele voorstelling tag-anchor Visuele voorstelling van tag-anchor


distance = ToF x (speed of light)  
ToF = ( (TRR-TSP) - (TSR-TRP) + (TRF-TSR) - (TSF-TRR) ) /4  
  
## Time Difference of Arrival

Bij deze techniek zijn de anchors met elkaar verbonden. De tag zendt een signaal uit dat de anchors ontvangen. Vanaf het eerst signaal is ontvangen wordt die tijd opgeslagen. als de andere tags het signaal ontvangen kijken ze hoeveel langer het had geduurt t.o.v. de tijd van het eerste ontvangen signaal.
  
## TWR vs TDoA
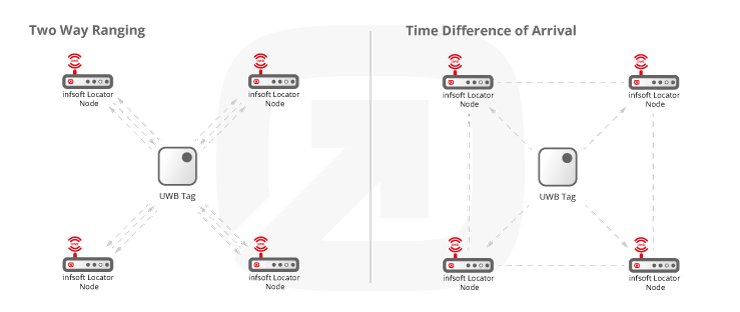
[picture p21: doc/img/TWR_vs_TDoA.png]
TWR vs TDoA Voorstelling tussen TWR & TDoA


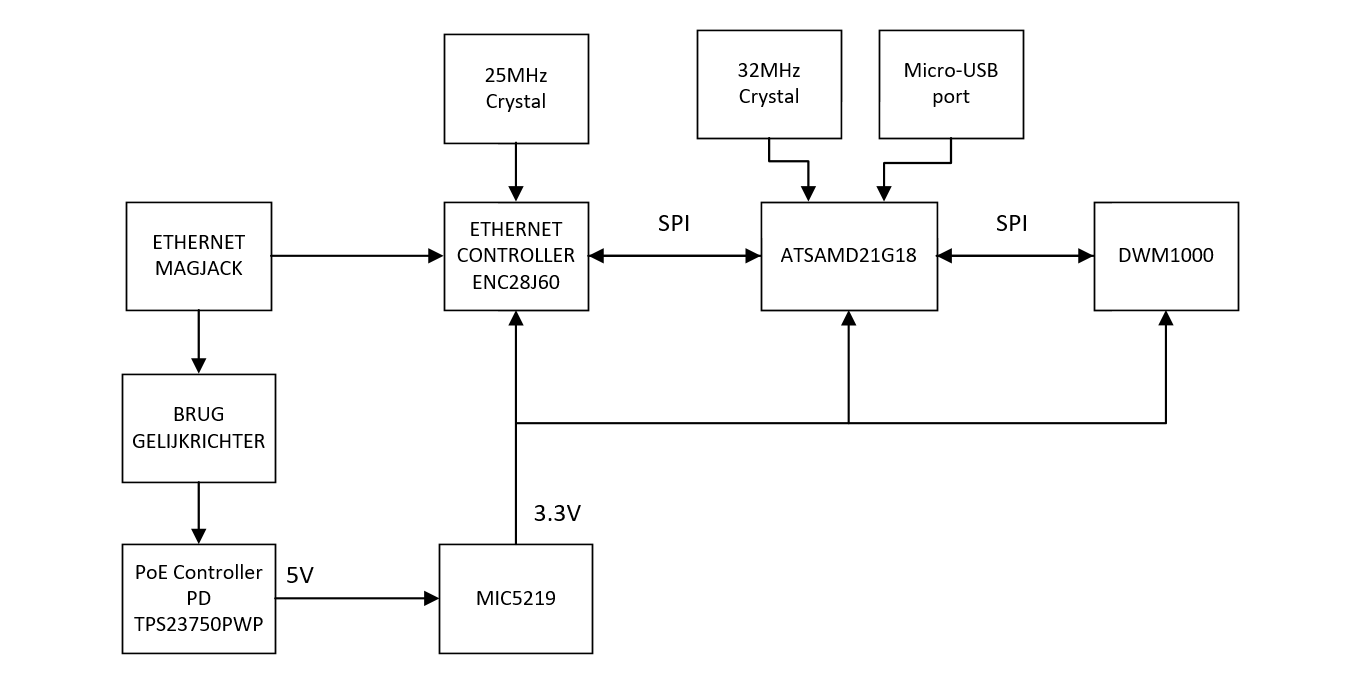
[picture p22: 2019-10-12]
doc/img/hardware-anchor.PNG

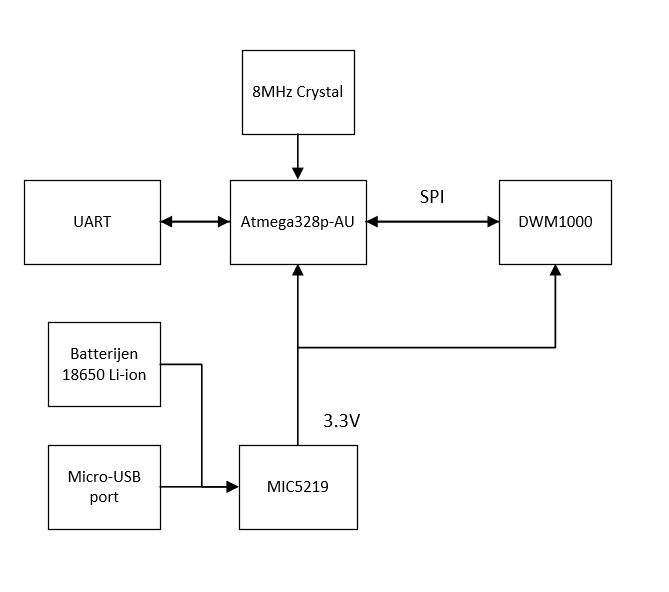
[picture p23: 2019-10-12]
doc/img/hardware-tagPNG.PNG

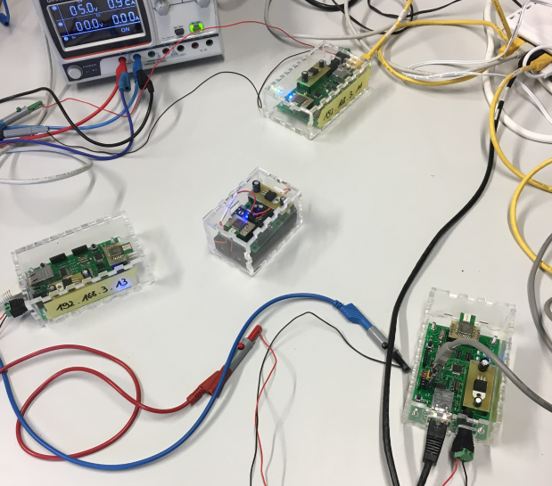
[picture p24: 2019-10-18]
src/visualisatie/WebAppLUWB/src/assets/img/APSelfMade.png

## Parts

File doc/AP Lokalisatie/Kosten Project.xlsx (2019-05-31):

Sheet: Totaal
 | Kosten LUWB Project |  | Eenheidsprijs | Aantal | Prijs | Link | Kosten POZYX Project | Prijs
Deze: | Switch Netgear ProSafe FS116P |  | €217.00 | 1 | €217.00 | https://www.coolblue.be/nl/product/311361/netgear-prosafe-fs116p.html
anders: | PoE switch - Edimax (100 Mbps, 8 poorten) |  | €77.50 | 2 | €155.00 | https://www.kabelshop.nl/Edimax-PoE-switch-Edimax-100-Mbps-8-poorten-ES-1008PHV2-i7402-t25867.html
 | Anchor |  | €39.75 | 4 | €159.00 | Zie blad Anchor
 |  |  |  |  | €0.00
 |  |  |  |  | €0.00
 |  |  |  |  | €0.00
 |  |  |  |  | €0.00
 |  |  |  |  | €0.00
 |  |  |  |  | €0.00
 |  |  |  |  | €0.00
 |  |  |  |  | €0.00
 |  |  |  |  | €0.00
 |  |  |  |  | €0.00
 |  |  |  |  | €0.00
 |  |  |  |  | €0.00
 |  |  |  |  | €0.00
 |  |  |  |  | €0.00
 |  |  |  |  | €0.00
 |  |  |  |  | €0.00
 |  |  |  |  | €0.00
 |  |  |  |  | €0.00
 |  |  |  |  | €0.00
 |  |  |  |  | €0.00
 |  |  |  |  | €0.00
 |  |  |  |  | €0.00
 |  |  |  |  | €0.00
 |  |  |  |  | €0.00
Totale prijs LUWB Project: |  | €376.00 |  |  |  |  | Totale prijs POZYX Project | €0.00

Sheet: Anchor
Onderdeel | Waarde | Package | Beschrijving | Eenheidsprijs | Aantal | Prijs | Link
C1 | 100nF | SMD0805 | Aan RJ45 | €0.01 | 1 | €0.01
C2 | 100nF | SMD0805 | Aan RJ45 | €0.01 | 1 | €0.01
C3 | 18pF | SMD0805 | Crystal ATMEGA1 | €0.00 | 0 | €0.00
C4 | 18pF | SMD0805 | Crystal ATMEGA1 | €0.00 | 0 | €0.00
C5 | 18pF | SMD0805 | Crystal ATMEGA2 | €0.00 | 0 | €0.00
C6 | 18pF | SMD0805 | Crystal ATMEGA2 | €0.00 | 0 | €0.00
C7 | 10uF | SMD0805 | VCAP ENC28J60 | €0.01 | 1 | €0.01
C8 | 18pF | SMD0805 | Crystal ENCJ2860 | €0.01 | 1 | €0.01
C9 | 18pF | SMD0805 | Crystal ENCJ2860 | €0.01 | 1 | €0.01
C10 | 100nF | SMD0805 | RESET ATMEGA1 | €0.00 | 0 | €0.00
C11 | 100nF | SMD0805 | RESET ATMEGA2 | €0.00 | 0 | €0.00
D1 | BLAUW | SMD1206 | POWER | €0.06 | 1 | €0.06
D2 | ROOD | SMD1206 | STATUS | €0.06 | 1 | €0.06
D3 | GEEL | SMD1206 | TX | €0.06 | 1 | €0.06
D4 | GROEN | SMD1206 | RX | €0.06 | 1 | €0.06
D5 | GEEL | SMD1206 | DWM-TX | €0.06 | 1 | €0.06
D6 | GROEN | SMD1206 | DWM-RX | €0.06 | 1 | €0.06
IC3 | ENC28J60 | SOP65P780X200-28N | Ethernet IC | €2.51 | 1 | €2.51
J1 | SI-50154-F | SI-50154-F | Ethernet Jack | €0.00 | 0 | €0.00
J2 | ISP PROG 1 | 2x3 Pinheader | ISP PROG 1 | €0.50 | 1 | €0.50
J3 | ISP PROG 2 | 2x3 Pinheader | ISP PROG 2 | €0.00 | 0 | €0.00
J4 | PJ102AH | PJ102AH | DC Jack | €0.00 | 0 | €0.00
MCU 1 | ATMEGA328P-AU | QFP80P900X900X120-32N | ATMEGA1 | €0.00 | 0 | €0.00
MCU 2 | ATMEGA328P-AU | QFP80P900X900X120-32N | ATMEGA2 | €0.00 | 0 | €0.00
R1 | 100 | SMD0805 | Led Magjack | €0.01 | 1 | €0.01
R2 | 100 | SMD0805 | Led Magjack | €0.01 | 1 | €0.01
R3 | 49.9 | SMD1206 | Ethernet schema | €0.01 | 1 | €0.01
R4 | 49.9 | SMD1206 | Ethernet schema | €0.01 | 1 | €0.01
R5 | 49.9 | SMD1206 | Ethernet schema | €0.01 | 1 | €0.01
R6 | 49.9 | SMD1206 | Ethernet schema | €0.01 | 1 | €0.01
R7 | 10k | SMD0805 | RESET 1 PULLUP | €0.01 | 1 | €0.01
R8 | 10k | SMD0805 | RESET 2 PULLUP | €0.00 | 0 | €0.00
R9 | 10k | SMD0805 | IRQ Pulldown | €0.01 | 1 | €0.01
R10 | 2k32 | SMD1206 | RBIAS ENCJ2860 | €0.01 | 1 | €0.01
R11 | 330 | SMD0805 | SPI VOORSCHAKEL | €0.01 | 1 | €0.01
R12 | 330 | SMD0805 | SPI VOORSCHAKEL | €0.01 | 1 | €0.01
R13 | 330 | SMD0805 | SPI VOORSCHAKEL | €0.01 | 1 | €0.01
R17 | 470 | SMD1206 | R LED Power | €0.01 | 1 | €0.01
R18 | 220 | SMD1206 | R LED RX | €0.01 | 1 | €0.01
R19 | 270 | SMD1206 | R LED TX | €0.01 | 1 | €0.01
R20 | 390 | SMD1206 | R LED STATUS | €0.01 | 1 | €0.01
R21 | 270 | SMD1206 | R LED DWM-TX | €0.01 | 1 | €0.01
R22 | 220 | SMD1206 | R LED DWM-RX | €0.01 | 1 | €0.01
S1 | RESET 1 | MOMENTARY-SWITCH-SPST-PTH-6.0MM | Reset 1 | €2.25 | 1 | €2.25
S2 | RESET 2 | MOMENTARY-SWITCH-SPST-PTH-6.0MM | Reset 2 | €0.00 | 0 | €0.00
DC-STEPDOWN | DC-STEPDOWN | DC-STEPDOWN | Power module | €3.00 | 1 | €3.00
DWM1000 | DWM1000 | DWM1000 | UWB Module | €21.73 | 1 | €21.73
UART1 | UART1 | 1x6 Pinheader | UART1 | €0.32 | 1 | €0.32
UART2 | UART2 | 1x6 Pinheader | UART2 | €0.00 | 0 | €0.00
Y1 | 8MHz | HC49UP | Crystal ATMEGA1 | €0.00 | 0 | €0.00
Y2 | 8MHz | HC49UP | Crystal ATMEGA2 | €0.00 | 0 | €0.00
Y3 | 25MHz | HC49UP | Crystal ENCJ2860 | €0.75 | 1 | €0.75
ATSAMD21G18A-AU | ATSAMD21G18A-AU |  | ATSAMD21G18A-AU | €2.21 | 1 | €2.21 | https://www.microchip.com/wwwproducts/en/ATsamd21g18
507-1421-ND | RJ45 Ethernet |  | RJ45 Ethernet | €4.70 | 1 | €4.70 | https://www.digikey.com/product-detail/en/bel-fuse-inc/0813-1X1T-57-F/507-1421-ND/2107986
Crystal 48MHz | 48MHz |  | Crystal 48MHz | €1.19 | 1 | €1.19 | https://nl.farnell.com/abracon/abm3b-48-000mhz-b2-t/crystal-48mhz-18pf-5-x-3-2mm/dp/2467815
Totale prijs LUWB Project: |  | €39.75

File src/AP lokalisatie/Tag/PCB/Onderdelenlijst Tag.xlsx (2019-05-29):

Onderdeel | Waarde | Package
C1 | 18pF | SMD0805
C2 | 18pF | SMD0805
C3 | 100nF | SMD0805
C4 | 100uF | 3.5-8
C5 | 10uF | 2.5-7
MCU 1 | ATMEGA328P-AU | QFP80P900X900X120-32N
J1 | ISP PROG | 2x3 Pinheader
Q1 | 8MHz | HC49UP
R1 | 10k | SMD0805
R2 | 10k | SMD0805
S1 | RESET 1 | MOMENTARY-SWITCH-SPST-PTH-6.0MM
DWM1000 | DWM1000 | DWM1000
UART | UART | 1x6 Pinheader

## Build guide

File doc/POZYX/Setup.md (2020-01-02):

# Pozyx opzetten met eigen software
## 1 Hardware
De anchors dienen op verschillende hoogtes gehangen te worden om een goede Z-positie te kunnen meten. Ook is het best om deze niet in een mooi vierkant en recht over elkaar te hangen om de accuratie te verbeteren.
Als alle anchors opgehangen zijn moeten de coördinaten van alle anchors genoteerd worden ten opzichte van een nul-punt.
Vervolgens moet er 1 anchor met USB-kabel verbonden worden met een Raspberry Pi. Al de andere anchors moeten enkel van stroom voorzien worden.

## 2 Software
Alle scripts die nodig zijn zijn te vinden in src/Pozyx/PozyxStandalone en dienen uitgevoerd te worden vanop de Raspberry Pi.

### 2.1 Config-files
#### 2.1.1 config.ini
Als config.ini niet bestaat of er zijn wijzigingen gebeurt, moet deze aangemaakt of gewijzigd worden met de genoteerde waarden. Hierin worden alle instellingen in verband met de ID's en coördinaten opgeslagen.

1. python3 createConfigFile.py
2. Vervolgens zal het script je door de verschillende vragen nemen en vragen of je deze wilt aanpassen. 
3. Of je al dan niet het geconnecteerde toestel aan de Raspberry Pi wilt aanpassen, en wat de ID dan is van dat achor.
4. Of je al dan niet het remote toestel (meestal de tag) wilt aanpassen, en wat de ID dan is van dat toestel.
5. En of je al dan niet de verschillende anchors wilt aanpassen, en wat de ID dan is van dat anchor alsook de X,Y en Z-coördinaten van dat anchor.

#### 2.1.2 export.ini
Als export.ini niet bestaat of er zijn wijzigingen gebeurt, moet deze aangemaakt of gewijzigd worden. Hierin worden alle instellingen in verband met het exporteren van de positie opgeslagen.

1. python3 createExportFile.py
2. Vervolgens zal het script je door de verschillende vragen nemen en de waarden vragen.
3. Of je al dan niet wilt exporteren naar een file en wat de file name dan is.
4. Of je al dan niet wilt exporteren via MQTT en wat de host, topic en clientID dan zijn.
5. Of je al dan niet wilt exporteren naar de API en wat de URL van de API dan is en wat de Mac naam van de tag dan is.

### 2.2 Discover Devices
Je kan nakijken of alle toestellen van stroom voorzien zijn, binnen bereik zijn en dezelfde UWB-settings hebben door dit script uit te voeren.

1. python3 discoverDevices.py

Als alle toestellen worden weergegeven zijn alle toestellen bereikbaar.

### 2.3 Setup Anchors
Door dit script uit te voeren worden de coördinaten van de anchors opgeslagen in het geheugen van de tag, die deze dan kan gebruiken voor het lokaliseren.

1. python3 setupAnchors.py
2. Eerst wordt de tag zijn lijst van gekende toestellen leeggemaakt.
3. Vervolgens worden de anchors en hun coördinaten die uit de config-file komen, aan de tag zijn lijst toegevoegd.
4. Dan is de tag gereed om gelokaliseerd te worden.

### 2.4 Positioneren
Dit script voert de uiteindelijke lokalisatie uit.

1. python3 positioningTag.py
2. De tag berekend zijn positie aan de hand van de anchors.
3. De positie wordt in de terminal geprint.
4. De positie wordt in de file opgeslagen (indien aan in de instellingen).
5. De positie wordt verstuurd via MQTT (indien aan in de instellingen).
6. De positie wordt met een call naar de API aangepast (indien aan in instellingen).

Dit script is gelooped en dient zelf gestopt te worden.

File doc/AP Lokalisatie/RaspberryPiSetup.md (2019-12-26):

# 1 Bij gebruik van listenAndPostScriptAPI.py (voorkeur)
## 1.1 Aanmaken nieuwe config.ini
Als de config.ini file niet bestaat, moet deze aangemaakt worden en de gevraagde waardes worden ingevuld.
1. python3 createConfigfile.py
2. De volgende waardes moeten nu allemaal zijn ingevuld: {tcp_ip}, {tcp_port} en {api_url}. De andere waardes zijn niet belangrijk en mogen leeg gelaten worden.
## 1.2 Uitvoeren van listenAndPostScriptAPI.py
Als de config.ini bestaat, kan het Post script worden uitgevoerd. Deze begint te luisteren naar het ingestelde ip met poortnummer.
Als een anchor nieuwe informatie stuurt zal dit worden doorgestuurd naar de api met de ingestelde api_url.
- python3 listenAndPostScriptAPI.py
# 2 Bij gebruik van listAndPostScriptMQTT.py (2de voorkeur)
## 2.1 Aanmaken nieuwe config.ini
Als de config.ini file niet bestaat, moet deze aangemaakt worden en de gevraagde waardes worden ingevuld.
1. python3 createConfigfile.py
2. {invullen van alle waardes} Enkel de waarde van de {api_url} is niet van belang bij het gebruiken van dit script.
## 2.2 Uitvoeren van listenAndPostScriptMQTT.py
Als de config.ini bestaat, kan het MQTT script worden uitgevoerd. Deze begint te luisteren naar het ingestelde ip met poortnummer.
Als een anchor nieuwe informatie stuurt zal dit worden doorgestuurd naar de ingesteulde topic op de ingestelde host via de ingestelde clientid.
- python3 listenAndPostScriptMQTT.py
# 3 Bij gebruik van postScriptMQTT met Apache2
## 3.1 Installeren van Apache2 en instellen voor gebruik index.php
### 3.1.1 Installeren van Apache2
1. sudo apt-get update
2. sudo apt-get install apache2  -y
3. test de webserver door naar de website http://localhost/ te gaan
### 3.1.2 Apache2 instellen voor PHP
1. sudo apt-get install php libapache2-mod-php -y
2. cd /var/www/html
3. Plaats hier het index.php bestand (aanmaken en kopiëren via sudo touch index.php / sudo nano index.php)
4. sudo rm index.html
5. sudo service apache2 restart
### 3.1.3 Aanpassen eigendomsrechten voor index.php script
1. sudo chown -R www-data:www-data /var/www/html
Indien de fout Unable to open file! tevoorschijn komt probeer volgende commando's:
- sudo chmod +w /var/www/html/data/
- sudo chmod 0744 index.php
- sudo service apache2 restart
## 3.2 Uitvoeren van postscriptMQTT.py
- python3 postscriptMQTT.py
Bij een result code 0 is de connectie met de ingestelde MQTT topic gelukt.

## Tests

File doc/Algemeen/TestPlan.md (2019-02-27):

# Test Plan
## Getting started
### Setup
1. Download de laatste firmware en Pozyx software: http://tray.cloud.pozyxlabs.com/  
2. Run de software  
3. Op het einde van de installatie wordt er gevraagdt om in te loggen of een account te maken  
4. Zorg ervoor dat de firmware minstens v1.3 is anders update je deze via deze link: https://www.pozyx.io/product-info/developer-tag/firmware  
5. Connecteer de tag of anchor met de computer met behulp van een USB-tag. Als het systeem het device detecteerdt dan wordt het icoontje blauw.
6. Nu kan je naar de web applicatie surfen: https://bapp.cloud.pozyxlabs.com

### Web application
Als het systeem correct is aangesloten open je de web applicatie en log je in.

## Setup and autocalibrate
### Setup screen
In het setup scherm is het mogelijk de anchors en het grondplan in te stellen.

### Discovering the anchors
Het eerste wat je moet doen is het detecteren van alle toestellen, dit doe je door op de knop "discover anchors and tags" te duwen. Deze worden nog niet direct weergegeven op de map want ze hebben nog geen coördinaten. Dit kan manueel of automatisch gebeuren.

### Uploading a floor plan
De applicatie laat he ttoe om een grondplan van de opstelling te uploaden. Momenteel kan je JPEG, PNG of GIF bestanden uploaden.

### Automatically determining the anchor coordinates
Het automatisch calibreren van de anchors laat snelle set-ups toe. Dit kan je doen in de calibratie tab. Momenteel werkt autocalibratie alleen als de hoogte is geweten is.  
Het process kan je starten door op de "start calibration" knop te drukken. Dit kan enige tijd duren. Als de calibratie klaar is dan zie je de opllossing op de kaart.

## Positioning
### Introduction
Als alle coördinaten ingesteld zijn, zou het positioneren automatisch moeten starten. Dit kan je zien in het visualisatie zien.

## Connect with MQTT
### Introduction
Als alles up en running is, kunnen we data uit het systeem halen en er iets mee doen. Dit kan gemakkelijk met het populaire MQTT protocol. MQTT is een IoT protocol dat de sensor data geeft met behulp van publish en subscribe methode. Door te subscribe op de posities, krijg je de nieuwste posities vanaf dat ze beschikbaar zijn.

### Connect with the local stream
Wanneer je de data nodig hebt op je lokale toestel, kan je direct verbinden met de software. Lokaal verbinden wordt aangeraden voor real-time applicaties door de zeer lage latency. Veel programeer talen hebben MQTT libraries(bv. Python).

### Connect through the cloud stream
Door te connecteren met de cloud, kan je de date overal ontvangen.

## Testen
### Up and Running
Eerst kijken we of alle anchors verbonden zijn met de PC en er connectie is.

### Tag Finding
Hier gaan we kijken of de Tag kan gevonden worden in het midden van de locatie.

### Moving
Dan kijken we of hij goed vindbaar is als deze zich verplaatst door de ruimte.

### Out of Bound
Hierbij testen we tot hoever de tag buiten de zone detecteerbaar is.

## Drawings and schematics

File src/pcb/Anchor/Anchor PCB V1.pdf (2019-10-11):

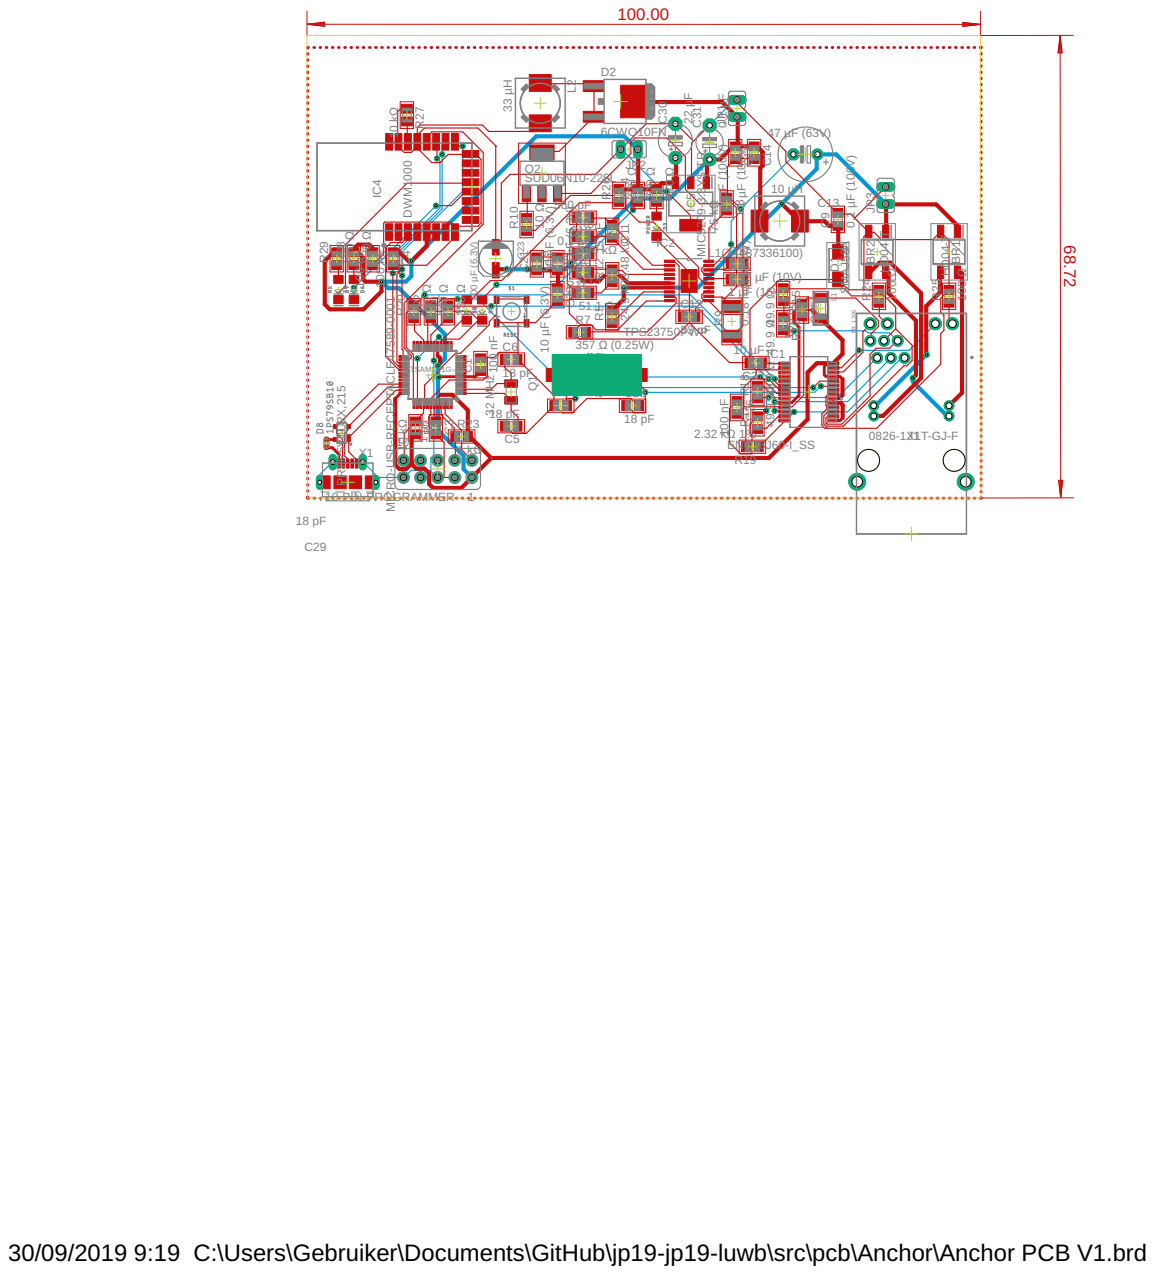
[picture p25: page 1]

30/09/2019 9:19 C:\Users\Gebruiker\Documents\GitHub\jp19-jp19-luwb\src\pcb\Anchor\Anchor PCB V1.brd

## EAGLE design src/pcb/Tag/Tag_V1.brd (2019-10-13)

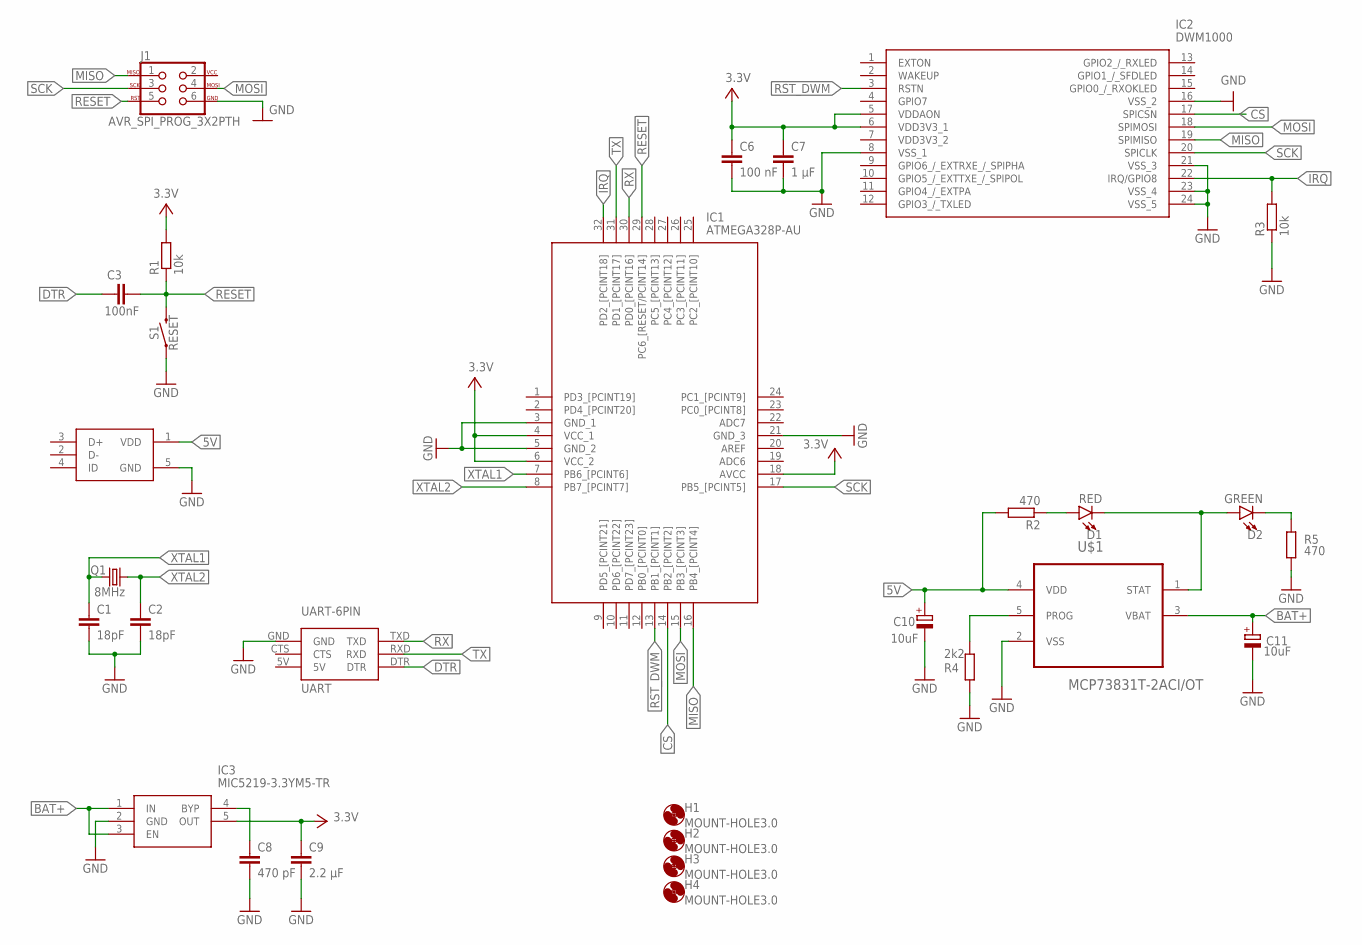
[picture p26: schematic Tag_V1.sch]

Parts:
C1, C2: 18pF; C0805
C3: 100nF; C0805
C6: 100 nF; C0805
C7: 1 µF; C0805
C8: 470 pF; C0805
C9: 2.2 µF; C0805
C10, C11: 10uF; E2,5-7
D1: RED; LED-1206
D2: GREEN; LED-1206
H1, H2, H3, H4: MOUNT-HOLE3.0; 3,0
IC1: ATMEGA328P-AU; QFP80P900X900X120-32N
IC2: DWM1000
IC3: MIC5219-3.3YM5-TR; SOT95P280X130-5N
J1: AVR_SPI_PROG_3X2PTH; 2X3
Q1: 8MHz; HC49UP
R1, R3: 10k; R0805
R2, R5: 470; R0805
R4: 2k2; R0805
S1: RESET; TACTILE_SWITCH_PTH_6.0MM
U1: 105017-0001; MOLEX_105017-0001
U$1: MCP73831T-2ACI/OT; SOT95P280X145-5N
U$2: UART-6PIN

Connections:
3.3V: C6.1, C7.1, C9.1, IC1.4 (VCC_1), IC1.6 (VCC_2), IC1.18 (AVCC), IC2.5 (VDDAON), IC2.6 (VDD3V3_1), IC3.5 (OUT), R1.2
5V: C10.+, R2.2, U1.1 (VDD), U$1.4 (VDD)
BAT+: C11.+, IC3.1 (IN), IC3.3 (EN), U$1.3 (VBAT)
CS: IC1.14 (PB2_[PCINT2]), IC2.17 (SPICSN)
DTR: C3.1, U$2.DTR
GND: C1.2, C2.2, C6.2, C7.2, C8.2, C9.2, C10.-, C11.-, IC1.3 (GND_1), IC1.5 (GND_2), IC1.21 (GND_3), IC2.8 (VSS_1), IC2.16 (VSS_2), IC2.21 (VSS_3), IC2.23 (VSS_4), IC2.24 (VSS_5), IC3.2 (GND), J1.6, R3.1, R4.2, R5.2, S1.1, U1.5 (GND), U$1.2 (VSS), U$2.GND
IRQ: IC1.32 (PD2_[PCINT18]), IC2.22 (IRQ/GPIO8), R3.2
MISO: IC1.16 (PB4_[PCINT4]), IC2.19 (SPIMISO), J1.1
MOSI: IC1.15 (PB3_[PCINT3]), IC2.18 (SPIMOSI), J1.4
unnamed: D1.C, D2.A, U$1.1 (STAT)
unnamed: D1.A, R2.1
unnamed: C8.1, IC3.4 (BYP)
unnamed: D2.C, R5.1
unnamed: R4.1, U$1.5 (PROG)
RESET: C3.2, IC1.29 (PC6_[RESET/PCINT14]), J1.5, R1.1, S1.3 (2)
RST_DWM: IC1.13 (PB1_[PCINT1]), IC2.3 (RSTN)
RX: IC1.30 (PD0_[PCINT16]), U$2.TXD
SCK: IC1.17 (PB5_[PCINT5]), IC2.20 (SPICLK), J1.3
TX: IC1.31 (PD1_[PCINT17]), U$2.RXD
XTAL1: C1.1, IC1.7 (PB6_[PCINT6]), Q1.1
XTAL2: C2.1, IC1.8 (PB7_[PCINT7]), Q1.2

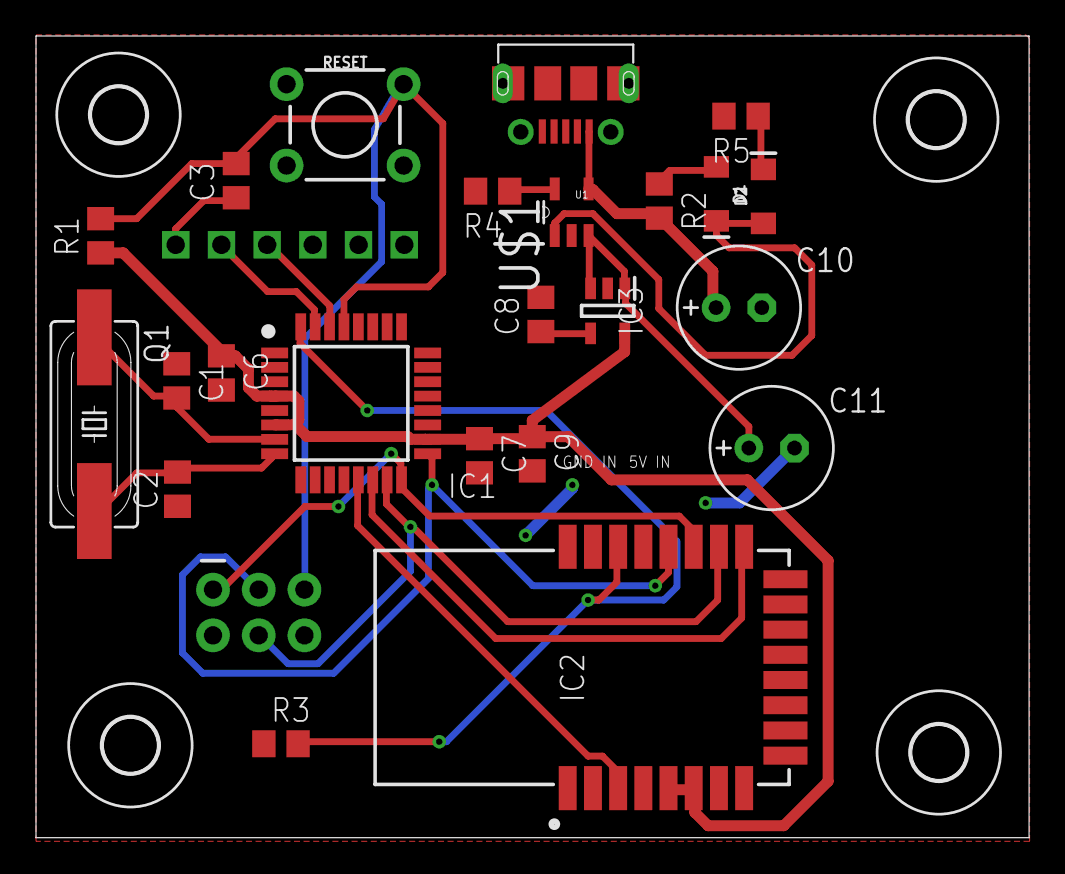
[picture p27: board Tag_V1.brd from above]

Board: 2 copper layers, 55.2 x 44.5 mm, 29 parts (1 on the bottom side), 21 nets.

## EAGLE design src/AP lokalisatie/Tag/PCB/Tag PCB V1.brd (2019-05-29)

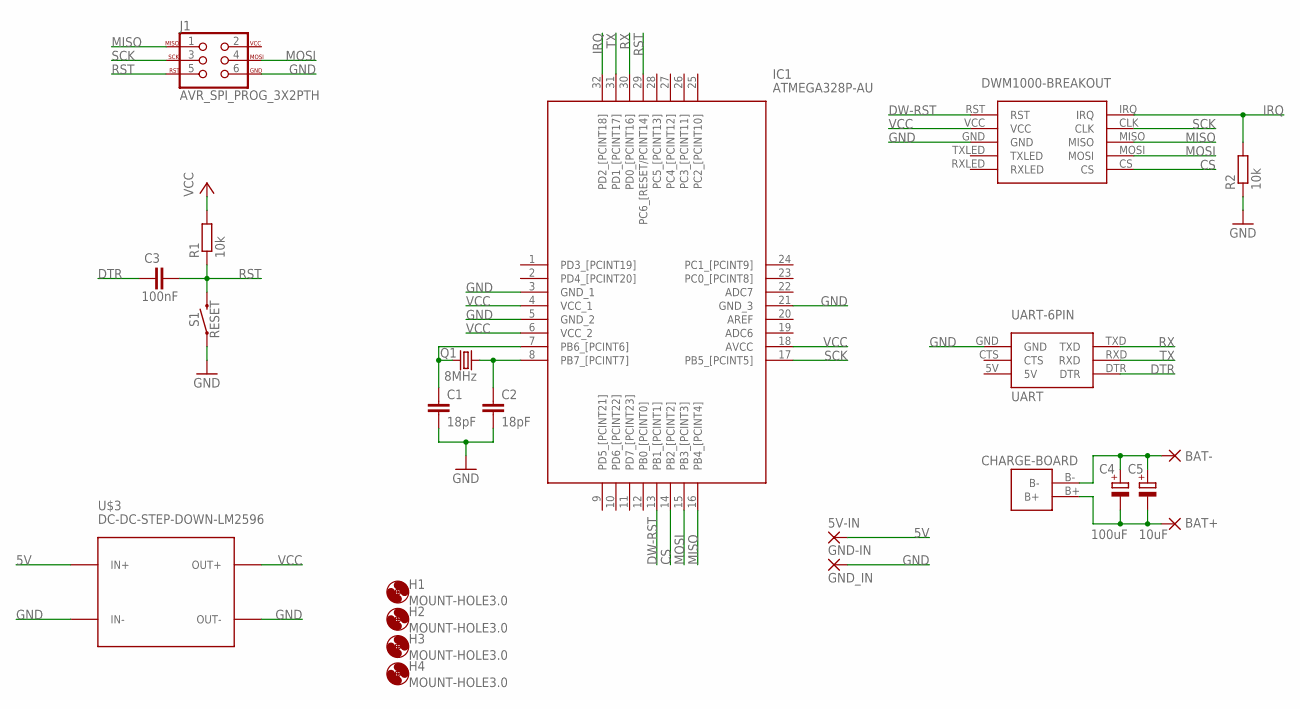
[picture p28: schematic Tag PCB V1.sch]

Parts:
5V-IN: 2,15/1,0
BAT+: 2,15/1,0
BAT-: 2,15/1,0
C1, C2: 18pF; C0805
C3: 100nF; C0805
C4: 100uF; E3,5-8
C5: 10uF; E2,5-7
GND-IN: GND_IN; 2,15/1,0
H1, H2, H3, H4: MOUNT-HOLE3.0; 3,0
IC1: ATMEGA328P-AU; QFP80P900X900X120-32N
J1: AVR_SPI_PROG_3X2PTH; 2X3
Q1: 8MHz; HC49UP
R1, R2: 10k; R0805
S1: RESET; TACTILE_SWITCH_PTH_6.0MM
U$1: DWM1000-BREAKOUT
U$2: UART-6PIN
U$3: DC-DC-STEP-DOWN-LM2596
U$4: 18650-CHARGE-5V-OUT

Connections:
5V: 5V-IN.1, U$3.IN+
CS: IC1.14 (PB2_[PCINT2]), U$1.CS
DTR: C3.1, U$2.DTR
DW-RST: IC1.13 (PB1_[PCINT1]), U$1.RST
GND: C1.2, C2.2, GND-IN.1, IC1.3 (GND_1), IC1.5 (GND_2), IC1.21 (GND_3), J1.6, R2.1, S1.1, U$1.GND, U$2.GND, U$3.IN-, U$3.OUT-
IRQ: IC1.32 (PD2_[PCINT18]), R2.2, U$1.IRQ
MISO: IC1.16 (PB4_[PCINT4]), J1.1, U$1.MISO
MOSI: IC1.15 (PB3_[PCINT3]), J1.4, U$1.MOSI
unnamed: BAT-.1, C4.+, C5.+, U$4.B-
unnamed: BAT+.1, C4.-, C5.-, U$4.B+
unnamed: C2.1, IC1.8 (PB7_[PCINT7]), Q1.2
unnamed: C1.1, IC1.7 (PB6_[PCINT6]), Q1.1
RST: C3.2, IC1.29 (PC6_[RESET/PCINT14]), J1.5, R1.1, S1.3 (2)
RX: IC1.30 (PD0_[PCINT16]), U$2.TXD
SCK: IC1.17 (PB5_[PCINT5]), J1.3, U$1.CLK
TX: IC1.31 (PD1_[PCINT17]), U$2.RXD
VCC: IC1.4 (VCC_1), IC1.6 (VCC_2), IC1.18 (AVCC), R1.2, U$1.VCC, U$3.OUT+

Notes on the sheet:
CHARGE-BOARD

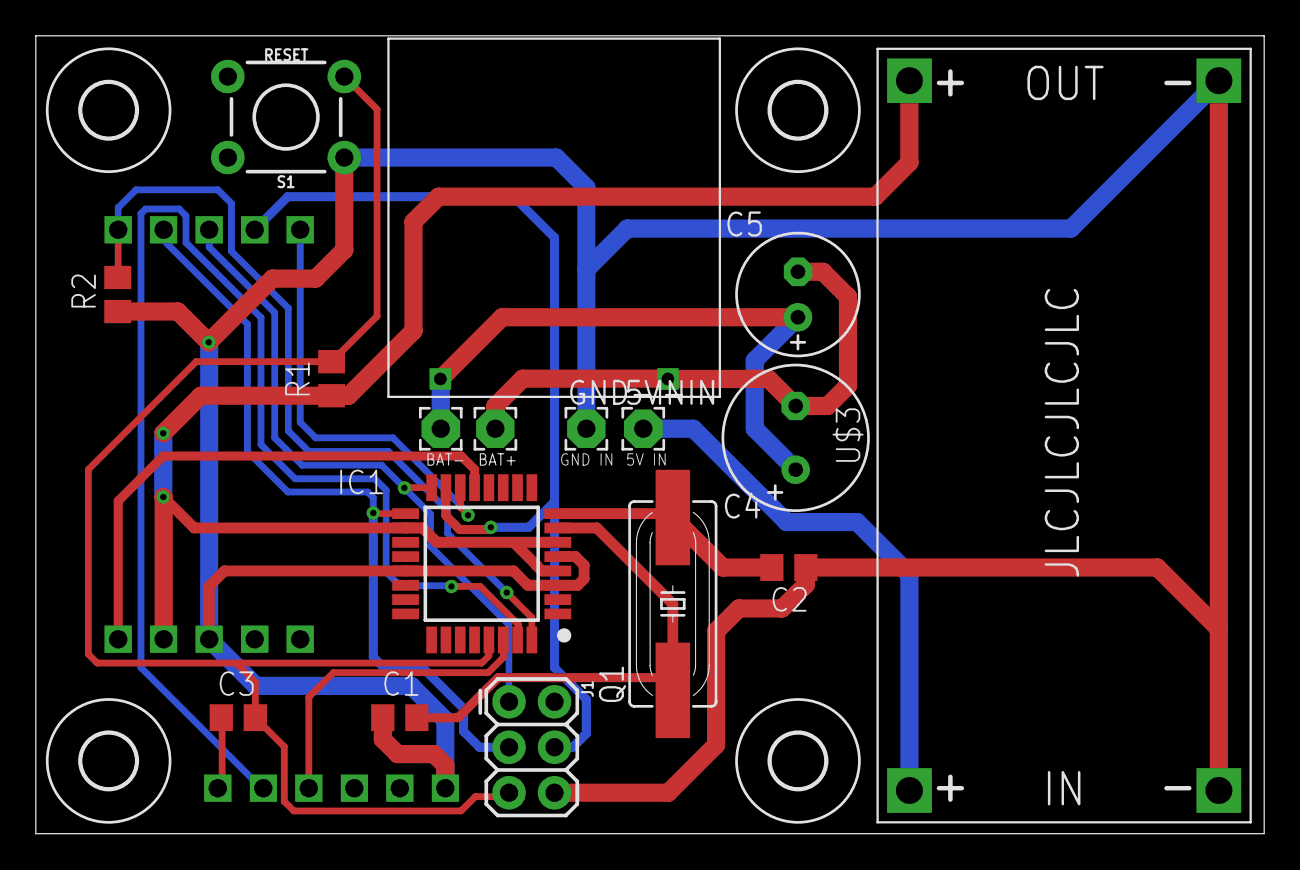
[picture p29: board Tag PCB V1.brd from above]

Board: 2 copper layers, 68.6 x 44.5 mm, 23 parts (0 on the bottom side), 17 nets.

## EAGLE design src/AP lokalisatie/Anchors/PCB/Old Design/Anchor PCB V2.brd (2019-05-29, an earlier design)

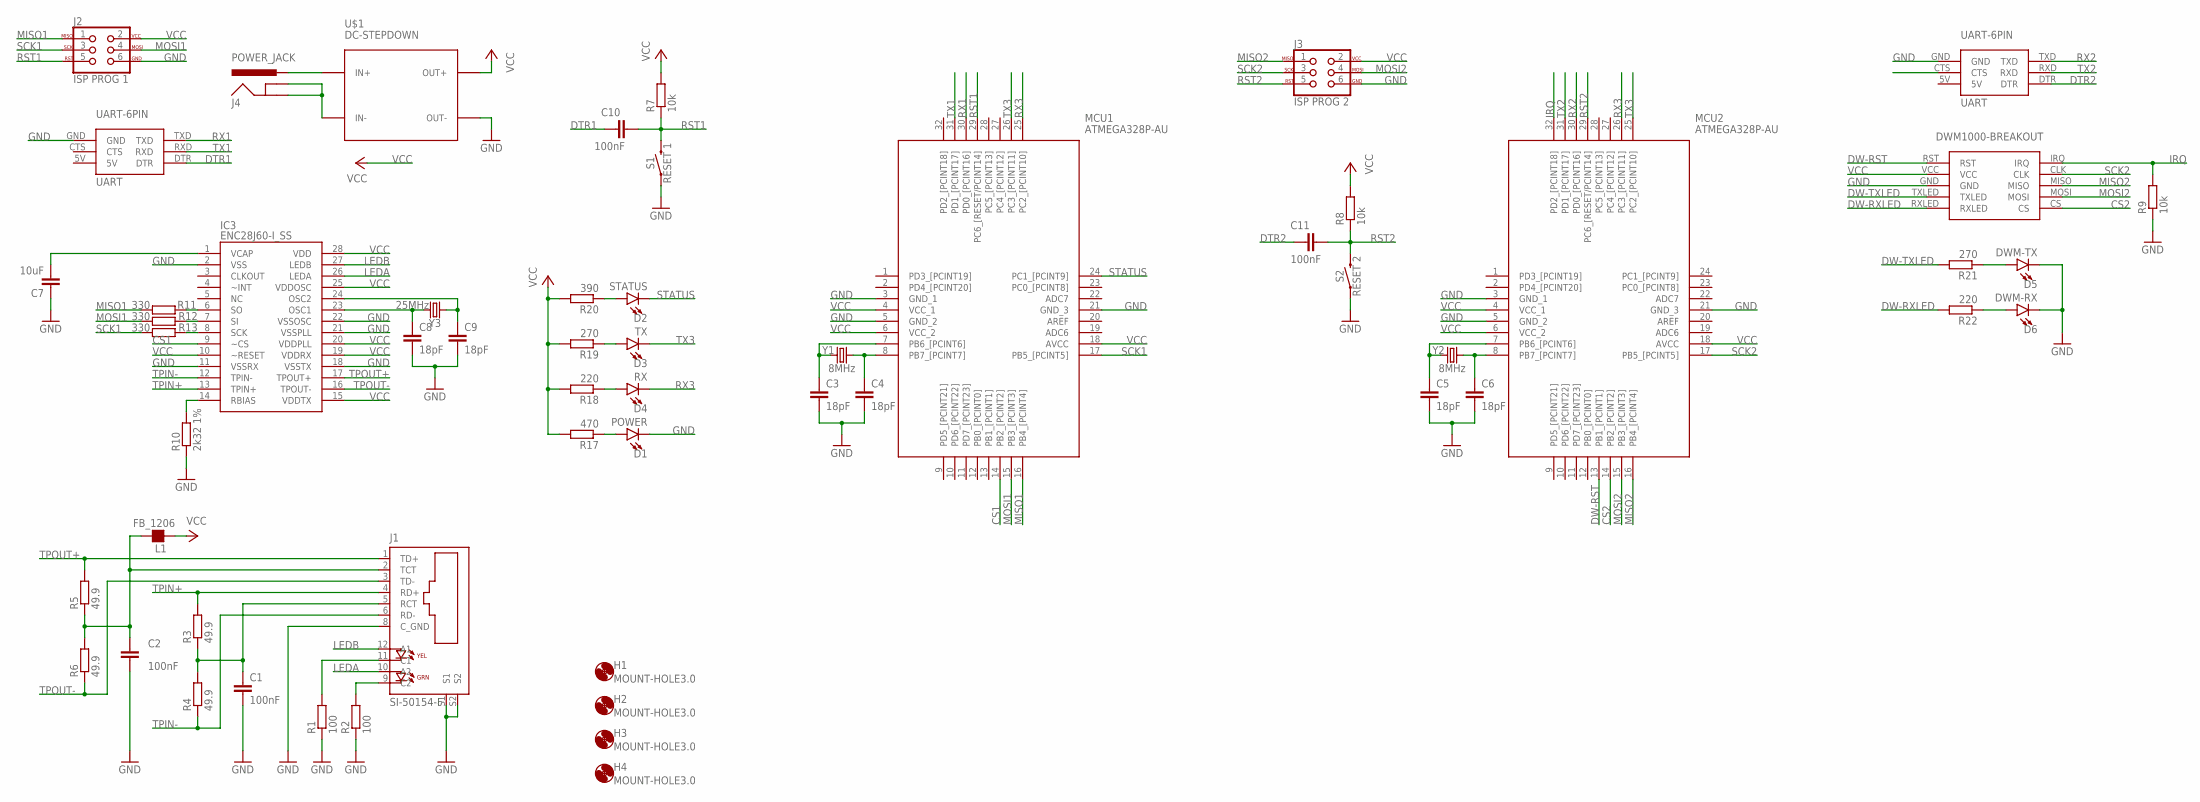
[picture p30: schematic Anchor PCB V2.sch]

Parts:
C1, C2, C10, C11: 100nF; C0805
C3, C4, C5, C6, C8, C9: 18pF; C0805
C7: 10uF; C0805
D1: POWER; LED-1206
D2: STATUS; LED-1206
D3: TX; LED-1206
D4: RX; LED-1206
D5: DWM-TX; LED-1206
D6: DWM-RX; LED-1206
H1, H2, H3, H4: MOUNT-HOLE3.0; 3,0
IC3: ENC28J60-I_SS; SOP65P780X200-28N
J1: SI-50154-F; STEWART_SI-50154-F
J2: ISP PROG 1; 2X3
J3: ISP PROG 2; 2X3
J4: POWER_JACK; POWER_JACK_PTH
L1: FB_1206; L1206
MCU1, MCU2: ATMEGA328P-AU; QFP80P900X900X120-32N
R1, R2: 100; R0805
R3, R4, R5, R6: 49.9; R1206
R7, R8, R9: 10k; R0805
R10: 2k32 1%; R1206
R11, R12, R13: 330; R0805
R17: 470; R1206
R18, R22: 220; R1206
R19, R21: 270; R1206
R20: 390; R1206
S1: RESET 1; TACTILE_SWITCH_PTH_6.0MM
S2: RESET 2; TACTILE_SWITCH_PTH_6.0MM
U$1: DC-STEPDOWN; DC-DC-STEP-DOWN-LM2596
U$2: DWM1000; DWM1000-BREAKOUT
UART1: UART1; UART-6PIN
UART2: UART2; UART-6PIN
Y1, Y2: 8MHz; HC49UP
Y3: 25MHz; HC49UP

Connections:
CS1: IC3.9 (~CS), MCU1.14 (PB2_[PCINT2])
CS2: MCU2.14 (PB2_[PCINT2]), U$2.CS
DTR1: C10.1, UART1.DTR
DTR2: C11.1, UART2.DTR
DW-RST: MCU2.13 (PB1_[PCINT1]), U$2.RST
DW-RXLED: R22.2, U$2.RXLED
DW-TXLED: R21.2, U$2.TXLED
GND: C1.2, C2.2, C3.2, C4.2, C5.2, C6.2, C7.1, C8.2, C9.2, D1.C, D5.C, D6.C, IC3.2 (VSS), IC3.11 (VSSRX), IC3.18 (VSSTX), IC3.21 (VSSPLL), IC3.22 (VSSOSC), J1.8 (C_GND), J1.S1, J1.S2, J2.6, J3.6, MCU1.3 (GND_1), MCU1.5 (GND_2), MCU1.21 (GND_3), MCU2.3 (GND_1), MCU2.5 (GND_2), MCU2.21 (GND_3), R1.1, R2.1, R9.1, R10.1, S1.1, S2.1, U$1.OUT-, U$2.GND, UART1.GND, UART2.GND
IN+: J4.PWR, U$1.IN+
IN-: J4.GND, J4.GNDBREAK, U$1.IN-
IRQ: MCU2.32 (PD2_[PCINT18]), R9.2, U$2.IRQ
LEDA: IC3.26 (LEDA), J1.10 (A2)
LEDB: IC3.27 (LEDB), J1.12 (A1)
MISO1: J2.1, MCU1.16 (PB4_[PCINT4]), R11.2
MISO2: J3.1, MCU2.16 (PB4_[PCINT4]), U$2.MISO
MOSI1: J2.4, MCU1.15 (PB3_[PCINT3]), R12.2
MOSI2: J3.4, MCU2.15 (PB3_[PCINT3]), U$2.MOSI
unnamed: J1.11 (C1), R1.2
unnamed: J1.9 (C2), R2.2
unnamed: C3.1, MCU1.7 (PB6_[PCINT6]), Y1.2
unnamed: C4.1, MCU1.8 (PB7_[PCINT7]), Y1.1
unnamed: C5.1, MCU2.7 (PB6_[PCINT6]), Y2.1
unnamed: C6.1, MCU2.8 (PB7_[PCINT7]), Y2.2
unnamed: C7.2, IC3.1 (VCAP)
unnamed: IC3.14 (RBIAS), R10.2
unnamed: C8.1, IC3.23 (OSC1), Y3.2
unnamed: C9.1, IC3.24 (OSC2), Y3.1
unnamed: IC3.6 (SO), R11.1
unnamed: C1.1, J1.5 (RCT), R3.1, R4.2
unnamed: C2.1, J1.2 (TCT), L1.2, R5.1, R6.2
unnamed: IC3.7 (SI), R12.1
unnamed: IC3.8 (SCK), R13.1
unnamed: D5.A, R21.1
unnamed: D4.A, R18.1
unnamed: D2.A, R20.1
unnamed: D3.A, R19.1
unnamed: D6.A, R22.1
unnamed: D1.A, R17.1
RST1: C10.2, J2.5, MCU1.29 (PC6_[RESET/PCINT14]), R7.1, S1.3 (2)
RST2: C11.2, J3.5, MCU2.29 (PC6_[RESET/PCINT14]), R8.1, S2.3 (2)
RX1: MCU1.30 (PD0_[PCINT16]), UART1.TXD
RX2: MCU2.30 (PD0_[PCINT16]), UART2.TXD
RX3: D4.C, MCU1.25 (PC2_[PCINT10]), MCU2.26 (PC3_[PCINT11])
SCK1: J2.3, MCU1.17 (PB5_[PCINT5]), R13.2
SCK2: J3.3, MCU2.17 (PB5_[PCINT5]), U$2.CLK
STATUS: D2.C, MCU1.24 (PC1_[PCINT9])
TPIN+: IC3.13 (TPIN+), J1.4 (RD+), R3.2
TPIN-: IC3.12 (TPIN-), J1.6 (RD-), R4.1
TPOUT+: IC3.17 (TPOUT+), J1.1 (TD+), R5.2
TPOUT-: IC3.16 (TPOUT-), J1.3 (TD-), R6.1
TX1: MCU1.31 (PD1_[PCINT17]), UART1.RXD
TX2: MCU2.31 (PD1_[PCINT17]), UART2.RXD
TX3: D3.C, MCU1.26 (PC3_[PCINT11]), MCU2.25 (PC2_[PCINT10])
VCC: IC3.10 (~RESET), IC3.15 (VDDTX), IC3.19 (VDDRX), IC3.20 (VDDPLL), IC3.25 (VDDOSC), IC3.28 (VDD), J2.2, J3.2, L1.1, MCU1.4 (VCC_1), MCU1.6 (VCC_2), MCU1.18 (AVCC), MCU2.4 (VCC_1), MCU2.6 (VCC_2), MCU2.18 (AVCC), R7.2, R8.2, R17.2, R18.2, R19.2, R20.2, U$1.OUT+, U$2.VCC

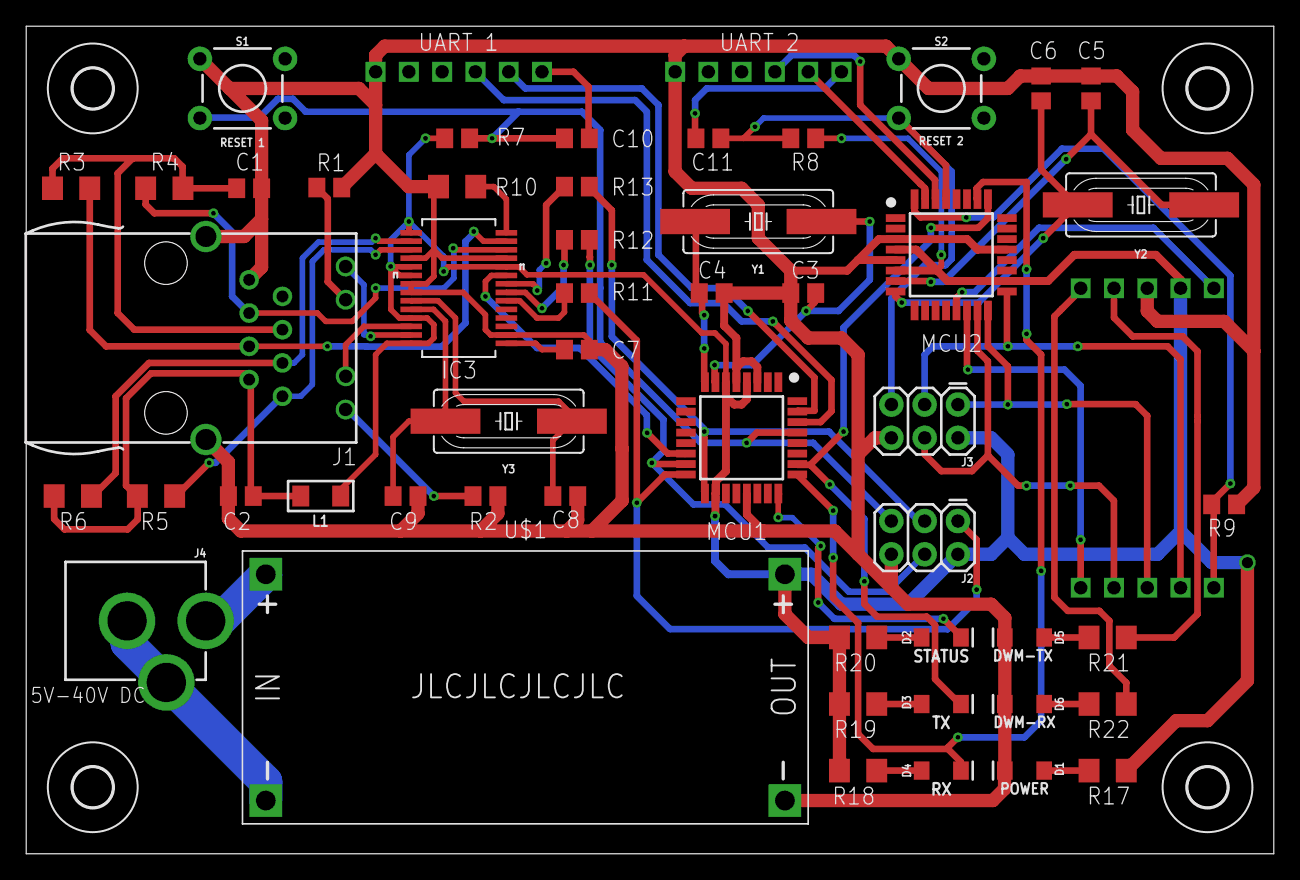
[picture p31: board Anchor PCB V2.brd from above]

Board: 2 copper layers, 95.2 x 63.2 mm, 57 parts (0 on the bottom side), 54 nets.

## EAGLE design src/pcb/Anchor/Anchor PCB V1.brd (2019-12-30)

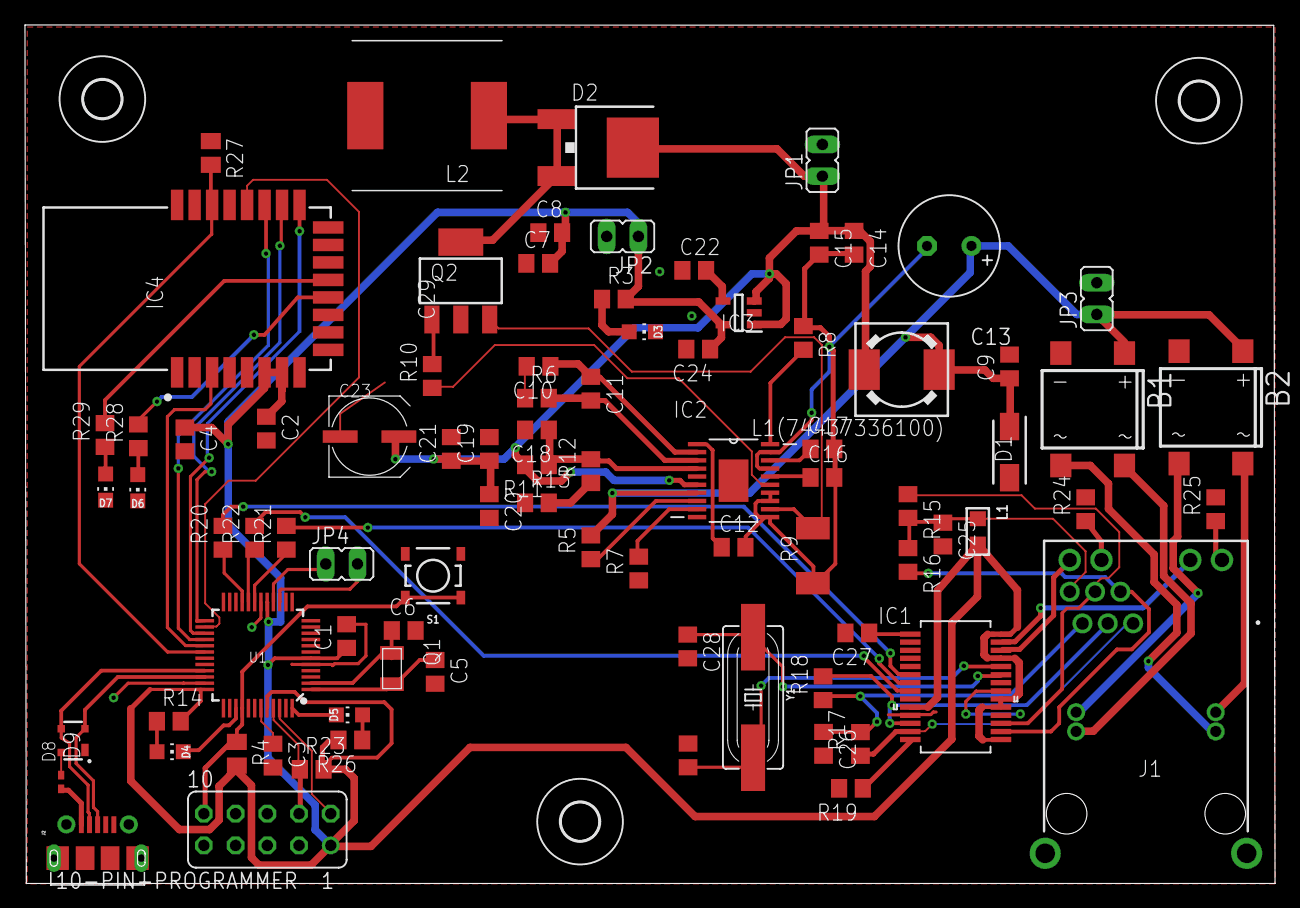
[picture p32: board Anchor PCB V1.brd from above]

Board: 2 copper layers, 100.1 x 68.7 mm, 89 parts (0 on the bottom side), 72 nets.

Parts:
10-PIN-PROGRAMMER: FE05-2
B1, B2: DBS103G; DBS
C1, C2, C4, C7, C25, C26: 100 nF; C0805
C3, C8: 1 µF; C0805
C5, C6, C28, C29: 18 pF; C0805
C9: 0.1 µF (100V); C0805
C10: 560 pF; C0805
C11: 15 pF; C0805
C12: 33 nF; C0805
C13: 47 µF (63V); E3,5-8
C14, C15: 1 µF (100V); C0805
C16: 1 µF (16V); C0805
C17: 0.22 µF (10V); C0805
C18: 0.1 µF; C0805
C19, C20, C21: 10 µF (6.3V); C0805
C22: 470 pF; C0805
C23: 100 µF (6.3V); UD-6,3X7,7_NICHICON
C24: 2.2 µF; C0805
C27: 10 µF; C0805
D1: SMAJ58A; DIOM5026X229N
D2: 6CWQ10FN; DPAK
D3: POWER; CHIP-LED0805
D4, D6: TX; CHIP-LED0805
D5, D7: RX; CHIP-LED0805
D8: 1PS79SB10; SOD523
D9: PRTR5V0U2X,215; SOT-143B
H1, H2, H3: MOUNT-HOLE3.0; 3,0
IC1: ENC28J60-I_SS; SOP65P780X200-28N
IC2: TPS23750PWP; SOP65P640X120-21N
IC3: MIC5219-3.3YM5-TR; SOT95P280X130-5N
IC4: DWM1000
J1: 0826-1X1T-GJ-F
J2: 105017-0001; MOLEX_105017-0001
JP1, JP2, JP3, JP4: JP1
L1: FB_0805; L0805
L1(74437336100): 10 µH; DR73
L2: 33 µH; WE-PD_1260/1245/1280/1210
Q1: 32 MHz; ABS07
Q2: SUD06N10-225L; SOT223
R3: 470 Ω; R0805
R4, R27: 10 kΩ; M0805
R5: 24,9 kΩ; R0805
R6: 100 kΩ; R0805
R7: 357 Ω (0.25W); R0805
R8: 75 kΩ; R0805
R9: 0.18 Ω (0.5W); R2010
R10: 10 Ω; R0805
R11: 1.5 kΩ; R0805
R12: 3.48 kΩ; R0805
R13: 51.1 Ω; R0805
R14, R28: 270 Ω; R0805
R15, R16, R17, R18: 49.9 Ω; R0805
R19: 2.32 kΩ 1%; R0805
R20, R21, R22: 330 Ω; R0805
R23: 1 kΩ; R0805
R24, R25: 100 Ω; R0805
R26, R29: 220 Ω; R0805
S1: RESET; TACTILE_SWITCH_SMD_4.5MM
U1: ATSAMD21G-A; TQFP-48
Y1: 25 MHz; HC49UP

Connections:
1_VC+: B2.AC1, J1.7
1_VC-: B2.AC2, J1.8
2_VC+: B1.AC2, J1.9
2_VC-: B1.AC1, J1.10
5V: C14.1, C15.1, C19.1, C20.1, C21.1, C23.+, D2.4, IC2.6, IC3.1, IC3.3, JP1.1, L1(74437336100).2, R11.2
48V: B1.+, B2.+, C9.1, C13.+, D1.1, IC2.7, JP3.1, L1(74437336100).1, R5.2
AUX: C16.1, IC2.16
COMP: C11.2, IC2.3, R6.2
COM_A_SHTKY: D2.1, D2.3, L2.1, Q2.4
CSN_DWM: IC4.17, U1.27
FB: C10.1, C11.1, IC2.2
FREQ: IC2.20, R8.2
GATE: IC2.15, R10.1
GND: 10-PIN-PROGRAMMER.3, 10-PIN-PROGRAMMER.5, 10-PIN-PROGRAMMER.9, B1.-, B2.-, C1.2, C2.2, C3.2, C4.2, C5.2, C6.2, C7.1, C8.1, C9.2, C18.2, C19.2, C20.2, C21.2, C22.1, C23.-, C24.2, C25.2, C26.2, C27.2, C28.2, C29.2, D1.2, D3.C, D6.C, D7.C, D9.1, IC1.2, IC1.11, IC1.18, IC1.21, IC1.22, IC2.10, IC2.21, IC3.2, IC4.8, IC4.16, IC4.21, IC4.23, IC4.24, J2.5, JP1.2, JP2.2, JP3.2, L2.2, R7.1, R13.1, R19.2, R24.2, R25.2, R27.1, S1.2, S1.3, U1.5, U1.18, U1.35, U1.42
GRN_CAT: J1.13, R24.1
GRN_LED: IC1.26, J1.14
IRQ: IC4.22, R27.2, U1.30
MISO1_MC: R20.1, U1.21
MISO2_DWM: IC4.19, U1.28
MOSI1_MC: R21.1, U1.19
MOSI2_DWM: IC4.18, U1.25
unnamed: C3.1, U1.43
unnamed: IC2.8, R5.1
unnamed: IC2.9, R7.2
unnamed: C25.1, J1.6, L1.1, R15.2, R16.1
unnamed: C10.2, R6.1
unnamed: C26.1, J1.3, R17.2, R18.1
unnamed: Q2.1, R10.2
unnamed: IC1.14, R19.1
unnamed: D3.A, R3.1
unnamed: R12.1, R13.2
unnamed: D4.A, R14.1
unnamed: D5.A, R26.1
unnamed: D6.A, R28.1
unnamed: D7.A, R29.1
unnamed: D8.1, D9.4
unnamed: C22.2, IC3.4
OSC1: C28.1, IC1.23, Y1.1
OSC2: C29.1, IC1.24, Y1.2
RESET: 10-PIN-PROGRAMMER.10, R4.1, S1.1, S1.4, U1.40
RSP: IC2.12, Q2.3, R9.2
RST_DWM: IC4.3, U1.29
RTN: C12.2, C13.-, C14.2, C15.2, C16.2, C17.2, IC2.11, IC2.13, IC2.14, IC2.17, IC2.19, R8.1, R9.1
RXLED_DWM: IC4.13, R29.2
RXLED_MC: D5.C, U1.48
RX_MC: JP4.1, U1.16
SCK1_MC: R22.1, U1.20
SCK2_DWM: IC4.20, U1.26
SCK_ETH: IC1.8, R22.2
SEN: C18.1, IC2.4, R11.1, R12.2
SI_ETH: IC1.7, R21.2
SO_ETH: IC1.6, R20.2
SWCLK: 10-PIN-PROGRAMMER.4, R23.1, U1.45
SWDIO: 10-PIN-PROGRAMMER.2, U1.46
TMR: C12.1, IC2.1
TPIN+: IC1.13, J1.1, R17.1
TPIN-: IC1.12, J1.2, R18.2
TPOUT+: IC1.17, J1.5, R15.1
TPOUT-: IC1.16, J1.4, R16.2
TXLED_DWM: IC4.12, R28.2
TXLED_MC: D4.C, U1.39
TX_MC: JP4.2, U1.15
USB+: D9.2, J2.3, U1.34
USB-: D9.3, J2.2, U1.33
VBIAS: C17.1, IC2.18
VBUS: D8.2, J2.1
VCAP: C27.1, IC1.1
VCC: 10-PIN-PROGRAMMER.1, C1.1, C2.1, C4.1, C7.2, C8.2, C24.1, IC1.10, IC1.15, IC1.19, IC1.20, IC1.25, IC1.28, IC3.5, IC4.6, IC4.7, JP2.1, L1.2, R3.2, R4.2, R14.2, R23.2, R26.2, U1.6, U1.17, U1.36, U1.44
XTAL1: C5.1, Q1.2, U1.1
XTAL2: C6.1, Q1.1, U1.2
YEL_CAT: J1.11, R25.1
YEL_LED: IC1.27, J1.12

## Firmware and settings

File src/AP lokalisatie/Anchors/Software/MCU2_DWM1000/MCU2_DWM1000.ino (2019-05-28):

/*
 * Copyright (c) 2015 by Thomas Trojer <thomas@trojer.net>
 * Decawave DW1000 library for arduino.
 *
 * Licensed under the Apache License, Version 2.0 (the "License");
 * you may not use this file except in compliance with the License.
 * You may obtain a copy of the License at
 *
 *     http://www.apache.org/licenses/LICENSE-2.0
 *
 * Unless required by applicable law or agreed to in writing, software
 * distributed under the License is distributed on an "AS IS" BASIS,
 * WITHOUT WARRANTIES OR CONDITIONS OF ANY KIND, either express or implied.
 * See the License for the specific language governing permissions and
 * limitations under the License.
 *
 * @file RangingTag.ino
 * Use this to test two-way ranging functionality with two DW1000. This is
 * the tag component's code which polls for range computation. Addressing and
 * frame filtering is currently done in a custom way, as no MAC features are
 * implemented yet.
 *
 * Complements the "RangingAnchor" example sketch.
 *
 * @todo
 *  - use enum instead of define
 *  - move strings to flash (less RAM consumption)
 */
uint8_t macAnchor = 3;

#include <SPI.h>
#include <DW1000.h>
#include <SoftwareSerial.h>
SoftwareSerial softSerial(A3, A2); // RX, TX
// connection pins
const uint8_t PIN_RST = 9; // reset pin
const uint8_t PIN_IRQ = 2; // irq pin
const uint8_t PIN_SS = SS; // spi select pin

// messages used in the ranging protocol
// TODO replace by enum
#define POLL 0
#define POLL_ACK 1
#define RANGE 2
#define RANGE_REPORT 3
#define RANGE_FAILED 255
// message flow state
volatile byte expectedMsgId = POLL;
// message sent/received state
volatile boolean sentAck = false;
volatile boolean receivedAck = false;
// protocol error state
boolean protocolFailed = false;
// timestamps to remember
DW1000Time timePollSent;
DW1000Time timePollReceived;
DW1000Time timePollAckSent;
DW1000Time timePollAckReceived;
DW1000Time timeRangeSent;
DW1000Time timeRangeReceived;
// last computed range/time
DW1000Time timeComputedRange;
// data buffer
#define LEN_DATA 18
byte data[LEN_DATA];

// watchdog and reset period
uint32_t lastActivity;
uint32_t resetPeriod = 50;
uint32_t lastHardActivity;
uint32_t hardresetPeriod = 3000;

// reply times (same on both sides for symm. ranging)
uint16_t replyDelayTimeUS = 4000;
// ranging counter (per second)
uint16_t successRangingCount = 0;
uint32_t rangingCountPeriod = 0;
float samplingRate = 0;

float calibrationValue = 0.9;

int afstand;

void setup() {
  // DEBUG monitoring
  Serial.begin(9600);
  softSerial.begin(9600);
  delay(1000);
  Serial.println(F("### DW1000-arduino-ranging-anchor ###"));
  // initialize the driver
  DW1000.begin(PIN_IRQ, PIN_RST);
  DW1000.select(PIN_SS);
  Serial.println(F("DW1000 initialized ..."));
  // general configuration
  DW1000.newConfiguration();
  DW1000.setDefaults();
  DW1000.setDeviceAddress(3);
  DW1000.setNetworkId(10);
  DW1000.enableMode(DW1000.MODE_LONGDATA_RANGE_ACCURACY);
  DW1000.commitConfiguration();
  Serial.println(F("Committed configuration ..."));
  // DEBUG chip info and registers pretty printed
  char msg[128];
  DW1000.getPrintableDeviceIdentifier(msg);
  Serial.print("Device ID: "); Serial.println(msg);
  DW1000.getPrintableExtendedUniqueIdentifier(msg);
  Serial.print("Unique ID: "); Serial.println(msg);
  DW1000.getPrintableNetworkIdAndShortAddress(msg);
  Serial.print("Network ID & Device Address: "); Serial.println(msg);
  DW1000.getPrintableDeviceMode(msg);
  Serial.print("Device mode: "); Serial.println(msg);
  // attach callback for (successfully) sent and received messages
  DW1000.attachSentHandler(handleSent);
  DW1000.attachReceivedHandler(handleReceived);

  
  DW1000.enableDebounceClock();
  DW1000.enableLedBlinking();
  DW1000.setGPIOMode(MSGP2, LED_MODE);
  DW1000.setGPIOMode(MSGP3, LED_MODE);

  
  
  // anchor starts in receiving mode, awaiting a ranging poll message
  receiver();
  noteActivity();
  // for first time ranging frequency computation
  rangingCountPeriod = millis();
}

void sendToEthernet(int tag, int distance){
  Serial.print(tag);
  Serial.print(",");
  Serial.println(distance);

  softSerial.print("<"); 
  softSerial.print(tag);
  softSerial.print(","); 
  softSerial.print(distance);
  softSerial.print(">");
}

void noteActivity() {
  // update activity timestamp, so that we do not reach "resetPeriod"
  lastActivity = millis();
  lastHardActivity = millis();
}

void resetInactive() {
  // anchor listens for POLL
  expectedMsgId = POLL;
  receiver();
  noteActivity();
}

void resetHardInactive() {
  DW1000.reset();
}

void handleSent() {
  // status change on sent success
  sentAck = true;
}

void handleReceived() {
  // status change on received success
  receivedAck = true;
}

void transmitPollAck() {
  DW1000.newTransmit();
  DW1000.setDefaults();
  data[0] = POLL_ACK;
  // delay the same amount as ranging tag
  DW1000Time deltaTime = DW1000Time(replyDelayTimeUS, DW1000Time::MICROSECONDS);
  DW1000.setDelay(deltaTime);
  DW1000.setData(data, LEN_DATA);
  DW1000.startTransmit();
}

void transmitRangeReport(float curRange) {
  DW1000.newTransmit();
  DW1000.setDefaults();
  data[0] = RANGE_REPORT;
  // write final ranging result
  memcpy(data + 1, &curRange, 4);
  DW1000.setData(data, LEN_DATA);
  DW1000.startTransmit();
}

void transmitRangeFailed() {
  DW1000.newTransmit();
  DW1000.setDefaults();
  data[0] = RANGE_FAILED;
  DW1000.setData(data, LEN_DATA);
  DW1000.startTransmit();
}

void receiver() {
  DW1000.newReceive();
  DW1000.setDefaults();
  // so we don't need to restart the receiver manually
  DW1000.receivePermanently(true);
  DW1000.startReceive();
}

/*
   RANGING ALGORITHMS
   ------------------
   Either of the below functions can be used for range computation (see line "CHOSEN
   RANGING ALGORITHM" in the code).
   - Asymmetric is more computation intense but least error prone
   - Symmetric is less computation intense but more error prone to clock drifts

   The anchors and tags of this reference example use the same reply delay times, hence
   are capable of symmetric ranging (and of asymmetric ranging anyway).
*/

void computeRangeAsymmetric() {
  // asymmetric two-way ranging (more computation intense, less error prone)
  DW1000Time round1 = (timePollAckReceived - timePollSent).wrap();
  DW1000Time reply1 = (timePollAckSent - timePollReceived).wrap();
  DW1000Time round2 = (timeRangeReceived - timePollAckSent).wrap();
  DW1000Time reply2 = (timeRangeSent - timePollAckReceived).wrap();
  DW1000Time tof = (round1 * round2 - reply1 * reply2) / (round1 + round2 + reply1 + reply2);
  // set tof timestamp
  timeComputedRange.setTimestamp(tof);
}

void computeRangeSymmetric() {
  // symmetric two-way ranging (less computation intense, more error prone on clock drift)
  DW1000Time tof = ((timePollAckReceived - timePollSent) - (timePollAckSent - timePollReceived) +
                    (timeRangeReceived - timePollAckSent) - (timeRangeSent - timePollAckReceived)) * 0.25f;
  // set tof timestamp
  timeComputedRange.setTimestamp(tof);
}

/*
   END RANGING ALGORITHMS
   ----------------------
*/

void loop() {

  int32_t curMillis = millis();
  if (!sentAck && !receivedAck) {
    // check if inactive
    if (curMillis - lastActivity > resetPeriod) {
      resetInactive();
    }
    if (curMillis - lastHardActivity > hardresetPeriod){
      resetHardInactive();
    }
    return;
  }
  // continue on any success confirmation
  if (sentAck) {
    sentAck = false;
    byte msgId = data[0];
    if (msgId == POLL_ACK) {
      DW1000.getTransmitTimestamp(timePollAckSent);
      noteActivity();
    }
  }
  if (receivedAck) {
    receivedAck = false;
    // get message and parse
    DW1000.getData(data, LEN_DATA);
    //for(int x=0; x<LEN_DATA; x++){
    //  Serial.print(data[x]);
    //  Serial.print(" ");
    //}
    //Serial.println();

    byte msgId = data[0];
    uint8_t msgAnchorMac = data[16];
    byte msgTagMac = data[17];
    
    if (msgId != expectedMsgId) {
      // unexpected message, start over again (except if already POLL)
      protocolFailed = true;
    }
    if (msgId == POLL && msgAnchorMac == macAnchor) {
      // on POLL we (re-)start, so no protocol failure
      protocolFailed = false;
      DW1000.getReceiveTimestamp(timePollReceived);
      expectedMsgId = RANGE;
      transmitPollAck();
      noteActivity();
    }
    else if (msgId == RANGE) {
      DW1000.getReceiveTimestamp(timeRangeReceived);
      expectedMsgId = POLL;
      if (!protocolFailed) {
        timePollSent.setTimestamp(data + 1);
        timePollAckReceived.setTimestamp(data + 6);
        timeRangeSent.setTimestamp(data + 11);
        // (re-)compute range as two-way ranging is done
        //computeRangeAsymmetric(); // CHOSEN RANGING ALGORITHM
        computeRangeSymmetric();
        transmitRangeReport(timeComputedRange.getAsMicroSeconds());
        long distance = (timeComputedRange.getAsMeters() - calibrationValue) * 100;
        
        /*Serial.print("Tag ");
        Serial.print(data[16]);
        Serial.print(": "); Serial.print(distance); Serial.println(" m");*/
        
        //softSerial.println((int)distance);
        //softSerial.print("#");

        sendToEthernet(msgTagMac,(int)distance); //SEND TAG MAC + TAG DISTANCE
        
        //Serial.print("\t RX power: "); Serial.print(DW1000.getReceivePower()); Serial.println(" dBm");
        //Serial.print("\t Sampling: "); Serial.print(samplingRate); Serial.println(" Hz");
        //Serial.print("FP power is [dBm]: "); Serial.println(DW1000.getFirstPathPower());
        //Serial.print("RX power is [dBm]: "); Serial.println(DW1000.getReceivePower());
        //Serial.print("Receive quality: "); Serial.println(DW1000.getReceiveQuality());
        // update sampling rate (each second)
        successRangingCount++;
        if (curMillis - rangingCountPeriod > 1000) {
          samplingRate = (1000.0f * successRangingCount) / (curMillis - rangingCountPeriod);
          rangingCountPeriod = curMillis;
          successRangingCount = 0;
        }
      }
      else {
        transmitRangeFailed();
      }

      noteActivity();
    }
  }
}

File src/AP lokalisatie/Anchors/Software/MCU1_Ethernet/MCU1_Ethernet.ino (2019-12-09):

#include <EtherCard.h>
#include <SoftwareSerial.h>
uint8_t macAnchor = 3; 
uint8_t macTag = 0;


static byte mymac[] = { 0x74, 0x69, 0x69, 0x2D, 0x30, 0x10 + macAnchor };
static byte myip[] = { 192, 168, 3, 10 + macAnchor }; //IP
static byte gwip[] = { 192, 168, 3, 3 }; //Gateway
static byte hisip[] = { 192, 168, 3, 3 }; //Destination
int hisport = 2000;
const char website[] PROGMEM = "192.168.3.3"; //Destination
byte Ethernet::buffer[500];
Stash stash;
static long timer;
static byte session;

int distance = 0;
int ethernetInterval = 100;


static boolean receiving = false;
static byte ndx = 0;
char startCharacter = '<';
char endCharacter = '>';
char readChar;
const byte charCount = 32;
char receivedChars[charCount];
char tempChars[charCount];
boolean newData = false;

SoftwareSerial softSerial(A3, A2); // RX, TX

void checkSerial() {

  while (softSerial.available() > 0 && newData == false) {
    readChar = softSerial.read();
    

    if (receiving == true) {
      if (readChar != endCharacter) {
        receivedChars[ndx] = readChar;
        ndx++;
        if (ndx >= charCount) {
          ndx = charCount - 1;
        }
      }
      else {
        receivedChars[ndx] = '\0'; // terminate the string
        receiving = false;
        ndx = 0;
        newData = true;
      }
    }

    else if (readChar == startCharacter) {
      receiving = true;
    }
  }
  if (newData == true) {
    strcpy(tempChars, receivedChars);
    splitSerialData();
    newData = false;
  }

}

void splitSerialData() {
  char * strtokIndex;
  strtokIndex = strtok(tempChars, ",");
  macTag = atoi(strtokIndex);

  strtokIndex = strtok(NULL, ",");
  distance = atoi(strtokIndex);

  Serial.print(macTag);
  Serial.print(",");
  Serial.println(distance);
}

void sendPacket() {



  byte sd = stash.create();
  stash.print("{");

  stash.print("\"MAC_TAG\":");
  stash.print("\"");
  stash.print("TAG");
  stash.print(macTag);
  stash.print("\"");
  stash.print(",");
  stash.print("\"MAC_ANCHOR\":");
  stash.print("\"");
  stash.print("ANCHOR");
  stash.print(macAnchor);
  stash.print("\"");
  stash.print(",");
  stash.print("\"DISTANCE\":");
  stash.print(distance);

  stash.print("}");
  stash.save();
  Stash::prepare(PSTR("POST http://$F HTTP/1.1" "\r\n"
                      "Host: $F" "\r\n"
                      "Content-Length: $D" "\r\n"
                      "Content-Type: application/json" "\r\n"
                      "\r\n"
                      "$H"),
                 website, website, stash.size(), sd);
  ether.tcpSend();


  Serial.print("Packet sent, distance: ");
  Serial.println(distance);
}
void setup () {
  Serial.begin(9600);
  Serial.println("\n[getStaticIP]");
  if (ether.begin(sizeof Ethernet::buffer, mymac) == 0)
    Serial.println( "Failed to access Ethernet controller");
  ether.staticSetup(myip, gwip);
  ether.copyIp(ether.hisip, hisip);
  ether.hisport = hisport;
  ether.printIp("Server: ", ether.hisip);
  softSerial.begin(9600);
}

void loop () {

  checkSerial();
  ether.packetLoop(ether.packetReceive());

  if (millis() > timer + ethernetInterval) {
    timer = millis();
    if (distance != 0) {
      sendPacket();
    }
  }


}

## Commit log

2017-02-17 Update timing.md
    invullen van de timing
2019-02-13 Create Software Flowchart
2019-02-20 State diagram app fix
    [state_diagram_app.xml]
2019-02-20 Update State diagram app
    [state_diagram_app.xml]
2019-02-27 Update State diagram
    [state_diagram_app.xml]
2019-02-27 Robot code has changed
    Arduino code for robot has changed :
    - Robot can turn 90 degrees to left/right with a time of 2103 ms.
2019-03-12 Initial Arduino + Android Studio
    Bluetooth connection + sending and receiving data
2019-03-12 Update buttons
    Animation buttons + refactoring
2019-03-13 App + Arduino expansion
    Android App:
    + Left and Right button added
    + Animation for all buttons
    - Changed App Icon
    + Buttons changed to ImageButtons
    Arduino:
    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
2019-03-13 Arduino bugfix
    -Direction fix
    [BluetoothConnectArduino.ino]
2019-03-20 Bugfixes
    - Fixed screen rotation bug (only portrait enabled)
    - Fixed button locations to be centered at all times
    + Added bluetooth stop signal on closing app or losing focus
2019-04-24 Update code measurementscontroller
    Changed code so that the distance can be updated through the raspberrypi
    Added a database intialiser so that the tags are added into the lists
2019-05-15 Adding software documentation
    - General information of software
    - Raspberry Pi setup information
2019-05-15 Server Mqtt part
    Added MQTT functionality inside the server with the help of a background thread.
2019-05-15 Integrate index.php into new python script
    Listening to socket and posting data on MQTT
2019-05-24 Optimizing listenAndPostScript + createConfigFile script
    - Optimized listenAndPostScript for the anchors.
    - Loading de config from config.ini
    - Creating config.ini with createConfigFile.py
    - Added Arduino software
2019-05-29 Fixing threading problem
    Adding comments to code
2019-05-29 Minimal configuration for ATSAMD21G18
    [Anchor PCB V1.brd, Anchor PCB V1.sch]
2019-05-29 Adding General documentation for AP lokalisait + datasheets
    + Added General documentation
    + Updated RaspberryPiSetup.md
    + Adding datasheets
2019-05-29 Updating software.md
    + Adding new method for Raspberry Pi
2019-05-29 Adding designs to Anchor + Tag + Arduino code for TAG
    + Added PCB Design
    + Added Case Design
    + Added parts lists
    + Added TAG arduino code
    [Anchor PCB V1.sch, Anchor PCB V2.brd, Anchor PCB V2.sch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]
2019-05-29 Added components
    Added DC DC converter
    Added reset button
    Added mini-USB connection
    [Anchor PCB V1.sch]
2019-05-31 Added costs of AP lokalisatie
    Just an estimate
    [Kosten Project.xlsx]
2019-09-11 Completed schematic anchor with PoE
    PCB design has not been done yet.
    Changes might happen in the future
    [Anchor PCB V1.brd, Anchor PCB V1.sch]
2019-09-11 Updated capacitor values XTAL
    [Anchor PCB V1.brd, Anchor PCB V1.sch]
2019-09-22 First version of PCB layout
    [Anchor PCB V1.brd, Anchor PCB V1.sch, Tag_V1.sch]
2019-09-30 Updating board
    Update board so that we are using parts that are available in the labo.
    [Anchor PCB V1.brd, Anchor PCB V1.sch]
2019-10-03 Final version of V1
    Added ground plane
    Some rewiring has been done.
    Swapping to MIC5219
    Changed USB-port
    [Anchor PCB V1.brd]
2019-10-03 Added mounting holes
    [Anchor PCB V1.brd, Anchor PCB V1.sch]
2019-10-04 Bug fixes ground plane
    [Anchor PCB V1.brd]
2019-10-04 Bugfixes clearances
    [Anchor PCB V1.brd]
2019-10-04 Bugfixes wiring
    Added PCB files
    Bugfixes
    [Anchor PCB V1.brd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]
2019-10-04 Added the add function of a tag/anchor
    + Able to add a tag/anchor
    + Error or success message when adding a tag/anchor
    + fontawesome icons are now useable
    + Bugfix with the numbers of items shown in the list when both tags and anchors are shown
    + Bugfix when changing sort by, number of items in list and visual items in the list where the Current page didn't go back to page 1.
    - Changed styling of the list of tags/anchors
    - Moved number of items in the list from settings page to the Tags/Anchors page
2019-10-04 Changed DC/DC to MIC5219
    [Tag_V1.brd, Tag_V1.sch]
2019-10-12 Final version
    Thicker traces where possible
    [Anchor PCB V1.brd]
2019-10-12 Final version V1 tag
    -Uses MIC5219 to convert 5V to 3.3V
    -DWM module is now soldered on the PCB
    [Tag_V1.brd, Tag_V1.sch]
2019-10-13 Added gerber files
    [Tag_V1.brd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]
2019-11-01 Adapter for burning bootloader V1
    [adapter.brd, adapter.sch]
2019-11-02 Added jumper for TX and RX of MCU
    [Anchor PCB V1.brd]
2019-11-04 Created gerber files adapter
    [copper_bottom.gbr, copper_top.gbr, drills.xln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]
2019-11-05 Added slider to change interval timer of the map
2019-11-15 Changed footprint 33µH
    [Anchor PCB V1.brd, Anchor PCB V1.sch]
2019-11-21 Update anchor wrong footprints
    [Anchor PCB V1.brd, Anchor PCB V1.sch]
2019-11-22 Rewiring and optimizing pcb layout
    [Anchor PCB V1.brd]
2019-11-23 Update footprints and wiring
    - update led footprints to 0805
    - update led pins tx rx atsamd21g18
    - moved header for tx and rx pins atsamd21g18
2019-11-23 Minor changes wiring
2019-11-23 Added backups for schematic and board
    [Anchor PCB V1.brd, Anchor PCB V1.sch]
2019-11-25 Saving preferences on switching route
2019-12-02 Solving connection problems
    [Anchor PCB V1.brd, Anchor PCB V1.sch]
2019-12-07 Changes wiring and added forgotten connections
    [Anchor PCB V1.brd, Anchor PCB V1.sch]
2019-12-16 Update doc RaspberryPiSetup for AP lokalisatie
2019-12-16 V2 Updaten mistakes
    [Anchor PCB V1.brd, Anchor PCB V1.sch]

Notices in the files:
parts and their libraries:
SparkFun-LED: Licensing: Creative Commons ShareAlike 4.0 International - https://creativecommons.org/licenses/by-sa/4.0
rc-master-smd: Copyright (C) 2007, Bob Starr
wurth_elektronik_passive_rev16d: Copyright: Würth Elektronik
